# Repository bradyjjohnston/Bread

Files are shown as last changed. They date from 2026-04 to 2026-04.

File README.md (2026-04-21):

# 🍞 SALT - Slice And Loaf Telemetry

> A modular home automation and environmental sensing platform, developed in collaboration with **EE4737** and the open-source [BREAD] project.

---

## Overview

BREAD is a modular embedded systems architecture built around a central **Loaf** board and hot-swappable **Slice** modules. Each slice handles its own sensing or control functionality and communicates back to the loaf over a shared protocol (UART). Together, they form a capable at-home weather station and automation hub.

---

## Architecture

```
┌────────────────────────────────────────┐
│              Loaf (Main Board)         │
│   Central controller with female conn. │
│   handles aggregation, display, logic  │
└────────┬────────┬────────┬─────────────┘
         │        │        │
    ┌────┴──┐ ┌───┴──┐ ┌───┴──┐
    │Slice 1│ │Slice2│ │Slice3│  ...
    │SENSE  │ │ ACT. │ │ OPT. │
    └───────┘ └──────┘ └──────┘
```

- **Loaf** — the main board with female connectors, acts as the central hub
- **Slices** — individual modules that plug into the loaf via edge connectors and expose sensor data or control outputs over UART/I2C

---

## Features

- 🌡️ **Environmental monitoring** — temperature, humidity, pressure (BME280)
- 🌐 **Weather data integration** — pulls external weather API data
- 📡 **Modular slice communication** — UART packet protocol between slices and loaf
- 🔌 **Plug-and-play expansion** — add new slices without redesigning the core system
- 🏠 **Home automation ready** — designed to grow into broader automation use cases

---

## Hardware

| Component | Role |
|---|---|
| LOAF | Sensor slice microcontroller |
| Sense Slice | temp / humidity / pressure sensor / boot sensor |
| Actuation Slice | salt distribution motor control |
| Optics Slice | camera processing and control |
| Power Slice | power outage detection and power distribution |

---

## Communication Protocol

Slices send formatted UART packets to the loaf via DMA when requested by the master MCU. Each packet includes:

- Formatted sensor data

---

## Getting Started

> ⚠️ Hardware required. Software setup instructions coming soon.

1. Clone this repo
2. Open in **STM32CubeIDE**
3. Flash the slice firmware to your Nucleo F303K8
4. Connect the slice to the loaf board via the edge connector
5. Monitor output over UART at `115200` baud

---

## Project Context

This system was developed as part of **EE4737** coursework and builds on the open-source BREAD framework. The goal is a practical, extensible platform for real-world embedded sensing and home automation experimentation.

---

## License

MIT — see `LICENSE` for details.

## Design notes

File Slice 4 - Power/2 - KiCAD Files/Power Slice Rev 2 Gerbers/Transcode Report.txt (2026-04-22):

   ---- Transcoding 'C:\Users\Emily\OneDrive\Desktop\College\Embedded Systems\Power Slice Rev 1\Power Slice Rev 2 Gerbers\Power Slice Rev 1-F_Paste.gbr' ----   Thu Feb 26 17:30:41 2026

D10   --> D100
D11   --> D101
D12   --> D102
D13   --> D103
D14   --> D104
D15   --> D105
D16   --> D106
D17   --> D107
D18   --> D108
D19   --> D109
D20   --> D110
D21   --> D111
D22   --> D112
D23   --> D113
D24   --> D114
D25   --> D115
D26   --> D116
D27   --> D117
D28   --> D118
D29   --> D119
D30   --> D120
D31   --> D121
D32   --> D122
D33   --> D123
D34   --> D124
D35   --> D125
D36   --> D126
D37   --> D127
-----------------------------------------------------------------

   ---- Transcoding 'C:\Users\Emily\OneDrive\Desktop\College\Embedded Systems\Power Slice Rev 1\Power Slice Rev 2 Gerbers\Power Slice Rev 1-F_Silkscreen.gbr' ----   Thu Feb 26 17:30:41 2026

D11   --> D128
D12   --> D129
D13   --> D130
D14   --> D131
D16   --> D132
D17   --> D133
D18   --> D134
-----------------------------------------------------------------

   ---- Transcoding 'C:\Users\Emily\OneDrive\Desktop\College\Embedded Systems\Power Slice Rev 1\Power Slice Rev 2 Gerbers\Power Slice Rev 1-In1_Cu.gbr' ----   Thu Feb 26 17:30:41 2026

D10   --> D135
D11   --> D136
D12   --> D137
D13   --> D138
D14   --> D139
D15   --> D140
D16   --> D141
D17   --> D142
D18   --> D143
D19   --> D144
D20   --> D145
D21   --> D146
D22   --> D147
D23   --> D148
D24   --> D149
D25   --> D150
D26   --> D151
D27   --> D152
D28   --> D153
D29   --> D154
D30   --> D155
D31   --> D156
D32   --> D157
-----------------------------------------------------------------

   ---- Transcoding 'C:\Users\Emily\OneDrive\Desktop\College\Embedded Systems\Power Slice Rev 1\Power Slice Rev 2 Gerbers\Power Slice Rev 1-In2_Cu.gbr' ----   Thu Feb 26 17:30:41 2026

D10   --> D158
D11   --> D159
D12   --> D160
D13   --> D161
D14   --> D162
D15   --> D163
D16   --> D164
D17   --> D165
D18   --> D166
D19   --> D167
D20   --> D168
D21   --> D169
D22   --> D170
D23   --> D171
D24   --> D172
D25   --> D173
D26   --> D174
D27   --> D175
D28   --> D176
D29   --> D177
D30   --> D178
D31   --> D179
D32   --> D180
D33   --> D181
D34   --> D182
D35   --> D183
-----------------------------------------------------------------

   ---- Transcoding 'C:\Users\Emily\OneDrive\Desktop\College\Embedded Systems\Power Slice Rev 1\Power Slice Rev 2 Gerbers\Power Slice Rev 1-B_Cu.gbr' ----   Thu Feb 26 17:30:41 2026

D10   --> D184
D11   --> D185
D12   --> D186
D13   --> D187
D14   --> D188
D15   --> D189
D16   --> D190
D17   --> D191
D18   --> D192
D19   --> D193
D20   --> D194
D21   --> D195
D22   --> D196
D23   --> D197
D24   --> D198
D25   --> D199
D26   --> D200
D27   --> D201
D28   --> D202
D29   --> D203
D30   --> D204
D31   --> D205
D32   --> D206
D33   --> D207
D34   --> D208
D35   --> D209
D36   --> D210
D37   --> D211
D38   --> D212
D39   --> D213
D40   --> D214
-----------------------------------------------------------------

   ---- Transcoding 'C:\Users\Emily\OneDrive\Desktop\College\Embedded Systems\Power Slice Rev 1\Power Slice Rev 2 Gerbers\Power Slice Rev 1-B_Mask.gbr' ----   Thu Feb 26 17:30:41 2026

D12   --> D215
D13   --> D216
D14   --> D217
D15   --> D218
D16   --> D219
D17   --> D220
D18   --> D221
D19   --> D222
D20   --> D223
D21   --> D224
D22   --> D225
D23   --> D226
D24   --> D227
D25   --> D228
D26   --> D229
D27   --> D230
D28   --> D231
D29   --> D232
D30   --> D233
D31   --> D234
-----------------------------------------------------------------

   ---- Transcoding 'C:\Users\Emily\OneDrive\Desktop\College\Embedded Systems\Power Slice Rev 1\Power Slice Rev 2 Gerbers\Power Slice Rev 1-B_Paste.gbr' ----   Thu Feb 26 17:30:41 2026

D10   --> D235
D11   --> D236
-----------------------------------------------------------------

   ---- Transcoding 'C:\Users\Emily\OneDrive\Desktop\College\Embedded Systems\Power Slice Rev 1\Power Slice Rev 2 Gerbers\Power Slice Rev 1-B_Silkscreen.gbr' ----   Thu Feb 26 17:30:41 2026

D10   --> D237
D11   --> D238
D12   --> D239
D13   --> D240
D14   --> D241
-----------------------------------------------------------------

   ---- Transcoding 'C:\Users\Emily\OneDrive\Desktop\College\Embedded Systems\Power Slice Rev 1\Power Slice Rev 2 Gerbers\Power Slice Rev 1-Edge_Cuts.gbr' ----   Thu Feb 26 17:30:41 2026

D10   --> D242
-----------------------------------------------------------------

   ---- Transcoding 'C:\Users\Emily\OneDrive\Desktop\College\Embedded Systems\Power Slice Rev 1\Power Slice Rev 2 Gerbers\Power Slice Rev 1-F_Cu.gbr' ----   Thu Feb 26 17:30:41 2026

D10   --> D243
D11   --> D244
D12   --> D245
D13   --> D246
D14   --> D247
D15   --> D248
D16   --> D249
D17   --> D250
D18   --> D251
D19   --> D252
D20   --> D253
D21   --> D254
D22   --> D255
D23   --> D256
D24   --> D257
D25   --> D258
D26   --> D259
D27   --> D260
D28   --> D261
D29   --> D262
D30   --> D263
D31   --> D264
D32   --> D265
D33   --> D266
D34   --> D267
D35   --> D268
D36   --> D269
D37   --> D270
D38   --> D271
D39   --> D272
D40   --> D273
D41   --> D274
D42   --> D275
D43   --> D276
D44   --> D277
D45   --> D278
D46   --> D279
D47   --> D280
D48   --> D281
D49   --> D282
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
-----------------------------------------------------------------

   ---- Transcoding 'C:\Users\Emily\OneDrive\Desktop\College\Embedded Systems\Power Slice Rev 1\Power Slice Rev 2 Gerbers\Power Slice Rev 1-PTH-drl_map.gbr' ----   Thu Feb 26 17:30:47 2026

D10   --> D292
D11   --> D293
D12   --> D294
D13   --> D295
D14   --> D296
-----------------------------------------------------------------

   ---- Transcoding 'C:\Users\Emily\OneDrive\Desktop\College\Embedded Systems\Power Slice Rev 1\Power Slice Rev 2 Gerbers\Power Slice Rev 1-PTH-drl.gbr' ----   Thu Feb 26 17:30:54 2026

D10   --> D297
D11   --> D298
D12   --> D299
D13   --> D300
D14   --> D301
D15   --> D302
D16   --> D303
D17   --> D304
D18   --> D305
D19   --> D306
-----------------------------------------------------------------

   ---- Transcoding 'C:\Users\Emily\OneDrive\Desktop\College\Embedded Systems\Power Slice Rev 1\Power Slice Rev 2 Gerbers\Power Slice Rev 1-PTH-drl_map.gbr' ----   Thu Feb 26 17:30:54 2026

D10   --> D307
D11   --> D308
D12   --> D309
D13   --> D310
D14   --> D311
-----------------------------------------------------------------

   ---- Transcoding 'C:\Users\Emily\OneDrive\Desktop\College\Embedded Systems\Power Slice Rev 1\Power Slice Rev 2 Gerbers\Power Slice Rev 1-NPTH-drl.gbr' ----   Thu Feb 26 17:30:55 2026

D10   --> D312
-----------------------------------------------------------------

   ---- Transcoding 'C:\Users\Emily\OneDrive\Desktop\College\Embedded Systems\Power Slice Rev 1\Power Slice Rev 2 Gerbers\Power Slice Rev 1-NPTH-drl_map.gbr' ----   Thu Feb 26 17:30:55 2026

D10   --> D313
D11   --> D314
D12   --> D315
D13   --> D316
-----------------------------------------------------------------

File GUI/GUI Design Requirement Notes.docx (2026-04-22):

Tasks:

- communication between host laptop and mcu
  - Pyserial: library to interact with mcu over serial wire or usb
    - https://pyserial.readthedocs.io/en/latest/
- hosting GUI on laptop inside:
  - Tkinter: simple easy to use python toolkit for building GUI which I have experience with
- Kalman Filter
  - https://thekalmanfilter.com/kalman-filter-explained-simply/
  - https://en.wikipedia.org/wiki/Kalman_filter
  - https://web.mit.edu/kirtley/kirtley/binlustuff/literature/control/Kalman%20filter.pdf
  - FilterPy
    - library with great documentation and specific kalman module that should simplify setup
    - https://filterpy.readthedocs.io/en/latest/kalman/KalmanFilter.html
  - https://www.geeksforgeeks.org/python/kalman-filter-in-python/
- Communication
  - collaborate with other teams in order to set up system on I2C commands:
    - one-byte for which part of project is being addressed
    - one-byte for communication or command being sent
    - additional bytes need to be determined for data transmit: decide max amount for one comm and use that
  - DMA on interrupt for receiving

Packet design for USB to MCU communication:

MCU:

Slice ID, 1 Byte

- first 4 bits= slice identification; second 4 bits slice portion command
  - 0x0 loaf
  - 0x1 actuation
    - 0x0 boot mechanism
    - 0x1 heating element
    - 0x2 salt spreading
  - 0x2 optics
    - 0x0 motion/presence
    - 0x1 snow height
    - 0x2 precipitation state
    - 0x3 level of light
  - 0x3 power
    - 0x0 power outage info
    - 0x1 power draw information
    - 0x2 E-stop
  - 0x4 sensing
    - 0x0 temperature info
    - 0x1 humidity info
    - 0x2 boot detection
    - 0x3 off-board weather data request

Length, 1 Byte:

- length of upcoming data bytes

Payload, variable length

- data to be transmitted

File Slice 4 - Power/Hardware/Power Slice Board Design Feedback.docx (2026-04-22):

General Comments

- Get rough power budgeting per slice (each board takes about 200 mA)
- Double-check footprints
- (Non-critical) Determine why the diodes are on the buck converter

Schematic

- Check footprints and match barrel jacks
- Need more amperage for the entire board (output 1.5 - 2A), make sure we can handle it
- Add another set of bulk capacitors on the 3v3 and 5v
- Tie MFP from the RTC to one of the Nucleo I/O pins, add a decoupling capacitor and pullup resistor to the MFP line
- Use a 36-pin edge connection symbol
- Find out the power draw on the 0-ohms and ensure that it can handle the current draw (0805 appears that it’s only rated for 1/8 W?)
- Slow-blow fuse for lines going out to the motors and actuation slice
- Add 3V3 and 5V inputs bypassing the bucks - need to add bypasses for the bucks (0-ohm jumper)

Board Design

- Move more elements to the back if possible
- Determine the amp limit through the edge connector, make sure that it is also limited with a fuse for safety (3A per contact)
  - Keep this conservative!
  - Put multiple traces for each 5V (?) to power each board
- Size traces and vias
- Add slits under each current sensor
- Use the recommended layout for the RTC
- Tune capacitors for the RTC
- Make the electrolytic capacitors traces thicker

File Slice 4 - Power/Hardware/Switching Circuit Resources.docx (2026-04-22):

https://electronics.stackexchange.com/questions/608611/switching-between-power-sources-part-2

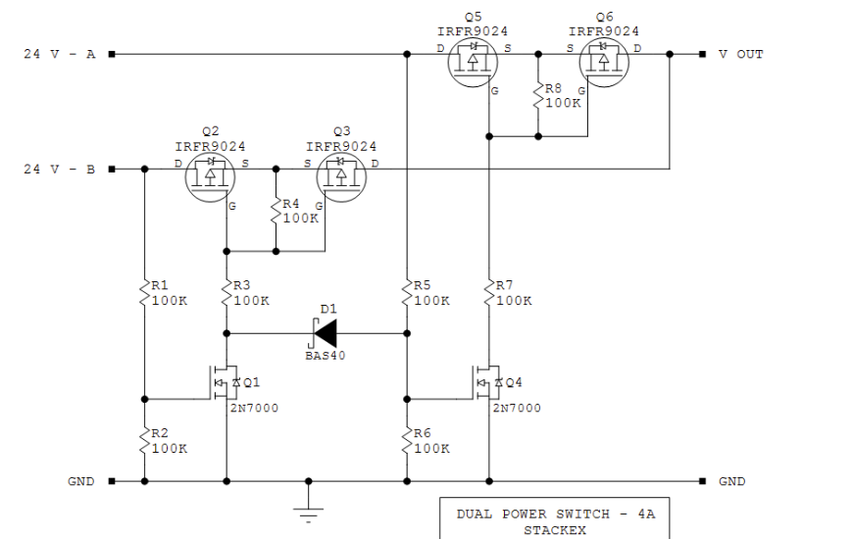
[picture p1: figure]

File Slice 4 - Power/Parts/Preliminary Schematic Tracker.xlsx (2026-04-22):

Subsystem | Parts Selected? | Schematic Created? | Responsibility
SLICE-LOAF Interface | In-Progress | No | N/A
Power Input: Benchtop | No | No | Emily
Power Input: Wall Power | No | No | Emily
Indicator LED | Yes | Yes | Joe
Outage Detection RTC | Yes | Yes | Joe
Full-System Circuit Break | In-Progress | No | Emily
Subsystem Circuit Break | In-Progress | No | Emily
3.3 V Conversion | In-Progress | No | Emily
5.0 V Conversion | In-Progress | No | Emily
Measured Power Draw | Yes | Yes | Joe
Displayed Power Draw | Yes | Yes | Joe

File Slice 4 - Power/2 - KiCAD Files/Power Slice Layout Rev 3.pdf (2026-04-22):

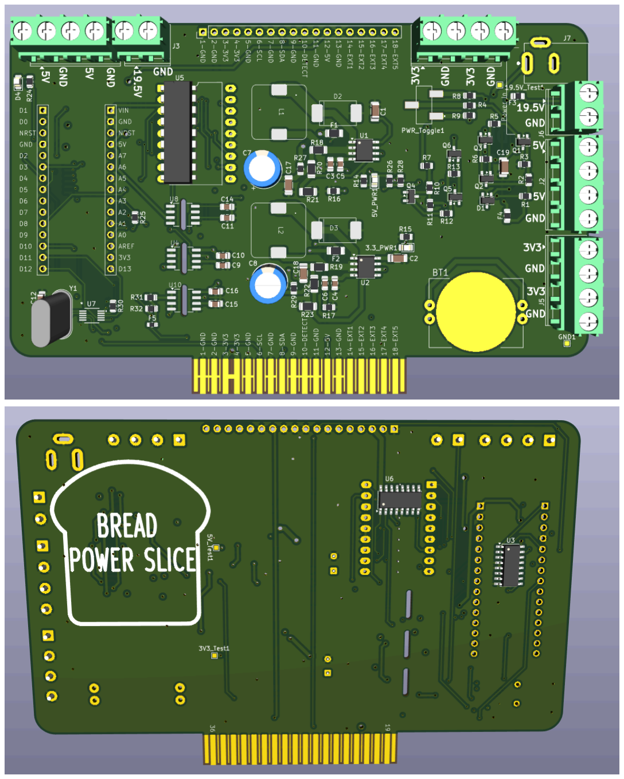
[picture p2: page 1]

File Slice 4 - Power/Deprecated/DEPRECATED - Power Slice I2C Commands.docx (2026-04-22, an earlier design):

The peripheral address of the Power Slice is 0x12.

The following are the commands that the LOAF can send the power slice via I2C:

| Command Value | Packet Length
Power Draw | 0xA | 4
Outage Time | 0xB | 4
Outage Since Last Transmission | 0xC | 1

Power Draw (0xA)

- Gives the power draw of the system in mW. WHAT IS THE ORDER OF DATA TRANSMISSION?

Outage Time (0xB)

- Gives the amount of time that the system has gone without power. If the outage time is zero, then the system has not lost power.
- INCLUDE THE DEFINITION OF EACH PIN / BYTE

Outage Since Last Transmission (0xC)

- Returns 0xF if there has been an outage since the last time this command has been run, and returns 0x0 otherwise.

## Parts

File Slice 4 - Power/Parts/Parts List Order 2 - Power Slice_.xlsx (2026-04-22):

Part | Function | Link | Footprint | Quantity | Datasheet? | Slice
SF-0603S040-2 | Fuse, 400 mA | https://www.digikey.com/en/products/detail/bourns-inc/SF-0603S040-2/8747904 | 603 | 5 | Yes | Power | X
CL31A106KBHNNNE | 10 uF Capacitor | https://www.digikey.com/en/products/detail/samsung-electro-mechanics/CL31A106KBHNNNE/3888534 | 1206 | 3 | Yes | Power | X
ACS725LLCTR-05AB-T | Current Sensor | https://www.digikey.com/en/products/detail/allegro-microsystems/ACS725LLCTR-05AB-T/10498747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..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 |  | 1 | Yes | Power | X
RC0805JR-070RL | 0-Ohm Jumper | https://www.digikey.com/en/products/detail/yageo/RC0805JR-070RL/728216 | 805 | 10 |  |  | X
SF-1206S150-2 | Fuse, 1.5 A | https://www.digikey.com/en/products/detail/bourns-inc/SF-1206S150-2/1948177 | 1206 | 4 |  |  | X
3413.0116.22 | Fuse, 1.25A | https://www.digikey.com/en/products/detail/schurter-inc/3413-0116-22/669877 | 1206 | 4

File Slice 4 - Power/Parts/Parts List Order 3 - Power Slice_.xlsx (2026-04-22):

Part | Function | Link | Footprint | Quantity | Datasheet? | Slice
n/a | Universal Laptop Charger | https://www.amazon.com/Certification-Universal-Compatible-Ultrabook-Chromebook/dp/B09NM28SB4 |  |  | No | Power | X
PJ-202BH | Power Barrel Connector Jack 2.50mm ID (0.098"), 5.50mm OD (0.217") Through Hole, Right Angle | https://www.digikey.com/en/products/detail/same-sky-formerly-cui-devices/PJ-202BH/408451 |  |  |  |  | X
PJ-202B | Power Barrel Connector Jack 2.50mm ID (0.098"), 5.50mm OD (0.217") Through Hole, Right Angle | https://www.digikey.com/en/products/detail/same-sky-formerly-cui-devices/PJ-202B/252008 |  |  |  |  | X
ADC-033-2 | Power Barrel Connector Jack 2.50mm ID (0.098"), 5.50mm OD (0.217") Through Hole, Right Angle | https://www.digikey.com/en/products/detail/adam-tech/ADC-033-2/9831639
KLDHCX-0202-BC-1 | Power Barrel Connector Jack 2.50mm ID (0.098"), 5.50mm OD (0.217") Through Hole, Right Angle | https://www.digikey.com/en/products/detail/kycon-inc/KLDHCX-0202-BC-1/13901306
KLDHCX-0202-B-LT | Power Barrel Connector Jack 2.50mm ID (0.098"), 5.50mm OD (0.217") Through Hole, Right Angle | https://www.digikey.com/en/products/detail/kycon-inc/KLDHCX-0202-B-LT/10246542

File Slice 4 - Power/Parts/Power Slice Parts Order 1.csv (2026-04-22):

Description | Part Number | Quantity | URL
RTC | MCP79510T-I/MS | 1 | https://www.digikey.com/en/products/detail/microchip-technology/MCP79510T-I-MS/3177022
Crystal Tuning Fork | VT200F-6PF20PPM | 1 | https://www.digikey.com/en/products/detail/seiko-instruments/VT200F-6PF20PPM/1626715
Buck Converter | L6902D013TR | 2 | https://www.digikey.com/en/products/detail/stmicroelectronics/L6902D013TR/1037941
Screw Terminal (4 port) | 1935187 | 4 | https://www.digikey.com/en/products/detail/phoenix-contact/1935187/568616
Screw Terminal (2 port) | 691137710002 | 2 | https://www.digikey.com/en/products/detail/w%C3%BCrth-elektronik/691137710002/6644051
Laptop Charger | n/a | 1 | https://www.amazon.com/Govolia-Charger-Compatible-Business-Convenient/dp/B081C8TRLP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
Diode, 3A Schottky | MBRS360T3G | 2 | https://www.digikey.com/en/products/detail/onsemi/MBRS360T3G/918646?s=N4IgTCBcDaILICEBKBlAzANgAwBU0HEQBdAXyA
Current Sensor | ACS725LLCTR-05AB-T | 2 | https://www.digikey.com/en/products/detail/allegro-microsystems/ACS725LLCTR-05AB-T/10498747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..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
0.1 uF/100nF - 0805 | CL21B104KBCNNNC | 7 | https://www.digikey.com/en/products/detail/samsung-electro-mechanics/CL21B104KBCNNNC/3886661
1 nF - 0805 | C0805C102J5GACTU | 5 | https://www.digikey.com/en/products/detail/kemet/C0805C102J5GACTU/411135
1 pF - 0805 | CML0805C0G1R0CT50V | 5 | https://www.digikey.com/en/products/detail/stackpole-electronics-inc/CML0805C0G1R0CT50V/10659964
10 pF - 0805 | QSCT251Q100J1GV001E | 5 | https://www.digikey.com/en/products/detail/johanson-technology-inc/QSCT251Q100J1GV001E/1833671
1k - 0805 | RMCF0805FT1K00 | 4 | https://www.digikey.com/en/products/detail/stackpole-electronics-inc/RMCF0805FT1K00/1760090
10k - 0805 | RMCF0805FT10K0 | 4 | https://www.digikey.com/en/products/detail/stackpole-electronics-inc/RMCF0805FT10K0/1760676
2x 7 Segment Display | LTD-6940HR | 1 | https://www.digikey.com/en/products/detail/liteon/LTD-6940HR/3199144
1x8 Multiplexer | NLV74ACT138DR2G | 2 | https://www.digikey.com/en/products/detail/onsemi/NLV74ACT138DR2G/5257279
3V Coin Cell | CR2032 | 2 | https://www.digikey.com/en/products/detail/panasonic-energy/CR2032/31939
Coin Cell Clip | BAT-HLD-001-THM | 1 | https://www.digikey.com/en/products/detail/te-connectivity-linx/BAT-HLD-001-THM/3044009
Barrel Jack | PJ-202A | 1 | https://www.digikey.com/en/products/detail/same-sky-formerly-cui-devices/PJ-202A/252007
LED - red - 0805 | LS R976-NR-1-0-20-R18 | 3 | https://www.digikey.com/en/products/detail/ams-osram-usa-inc/LS-R976-NR-1-0-20-R18/1227987
Mosfet | DMP2123L-7 | 6 | https://www.digikey.com/en/products/detail/diodes-incorporated/DMP2123L-7/1964692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
Fuse, 0.5A - 0805 | MFU0805FF00500P500 | 10 | https://www.digikey.com/en/products/detail/vishay/MFU0805FF00500P500/1202615
Fuse, 3.5A - 0805 | MFU0805FF03500P100 | 5 | https://www.digikey.com/en/products/detail/vishay/MFU0805FF03500P100/1206499
Fuse, 3A - 0805 | MFU0805FF03000P500 | 5 | https://www.digikey.com/en/products/detail/vishay/MFU0805FF03000P500/1202626
100k - 0805 | RC0805FR-07100KL | 11 | https://www.digikey.com/en/products/detail/yageo/RC0805FR-07100KL/727544
10uF - 1206 | CL31A106KBHNNNE | 5 | https://www.digikey.com/en/products/detail/samsung-electro-mechanics/CL31A106KBHNNNE/3888534
0.1 Ohm - 1206 | RL1206FR-070R1L | 4 | https://www.digikey.com/en/products/detail/yageo/RL1206FR-070R1L/2827660
0.2 Ohm - 1206 | RL1206FR-070R2L | 4 | https://www.digikey.com/en/products/detail/yageo/RL1206FR-070R2L/2827672
100uF - elec, 50V | UVK1H101MPD | 5 | https://www.digikey.com/en/products/detail/nichicon/UVK1H101MPD/2539403
3.3k - 0805 | RC0805FR-073K3L | 5 | https://www.digikey.com/en/products/detail/yageo/RC0805FR-073K3L/727813
4.3k - 1206 | RC1206FR-074K3L | 4 | https://www.digikey.com/en/products/detail/yageo/RC1206FR-074K3L/728872
220pF - 0805 | CL21C221JBANNNC | 5 | https://www.digikey.com/en/products/detail/samsung-electro-mechanics/CL21C221JBANNNC/3886822
5.1k - 0805 | RC0805FR-075K1L | 5 | https://www.digikey.com/en/products/detail/yageo/RC0805FR-075K1L/727988
22nF - 0805 | C0805C223K5RACTU | 5 | https://www.digikey.com/en/products/detail/kemet/C0805C223K5RACTU/411162
13k - 1206 | RC1206FR-0713KL | 4 | https://www.digikey.com/en/products/detail/yageo/RC1206FR-0713KL/728532
5.6k - 1206 | RC1206FR-075K6L | 4 | https://www.digikey.com/en/products/detail/yageo/RC1206FR-075K6L/728962
22uH - 8mm | P1171.223NLT | 2 | https://www.digikey.com/en/products/detail/pulse-electronics/P1171-223NLT/2266798
Diode, 200 mA Schotty | BAS40 | 1 | https://www.digikey.com/en/products/detail/diotec-semiconductor/BAS40/13155844
3.3k - 1206 | RC1206FR-073K3L | 4 | https://www.digikey.com/en/products/detail/yageo/RC1206FR-073K3L/728766
Switch | JS102011SCQN | 1 | https://www.digikey.com/en/products/detail/c-k/JS102011SCQN/3753547
0-0hm - 0805 | RC0805JR-070RL | 10 | https://www.digikey.com/en/products/detail/yageo/RC0805JR-070RL/728216

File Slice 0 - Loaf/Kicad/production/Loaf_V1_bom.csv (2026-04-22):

Designator | Footprint | Quantity | Value | LCSC Part #
C1, C17, C2, C7, C8 | 0805 | 5 | 0.1uF
C10, C11, C12, C13, C14, C15, C16, C3, C4, C5, C6, C9 | 0805 | 12 | 10uF
D1 | 0805 | 1 | USER LED1
D2 | 0805 | 1 | USER LED2
J1 | TerminalBlock_RND_205-00234_1x04_P5.08mm_Horizontal | 1 | Power Input Terminal
J2, J3, J4, J5 | EdgeConnector | 4 | 36p Edge Connector
R1, R2, R3, R4, R5, R6, R7, R8, R9 | 0805 | 9 | 4.7k
SW1 | SW_PUSH_6mm_H5mm | 1 | BOOT
U1 | MODULE_NUCLEO-F303K8 | 1 | NUCLEO-F303K8

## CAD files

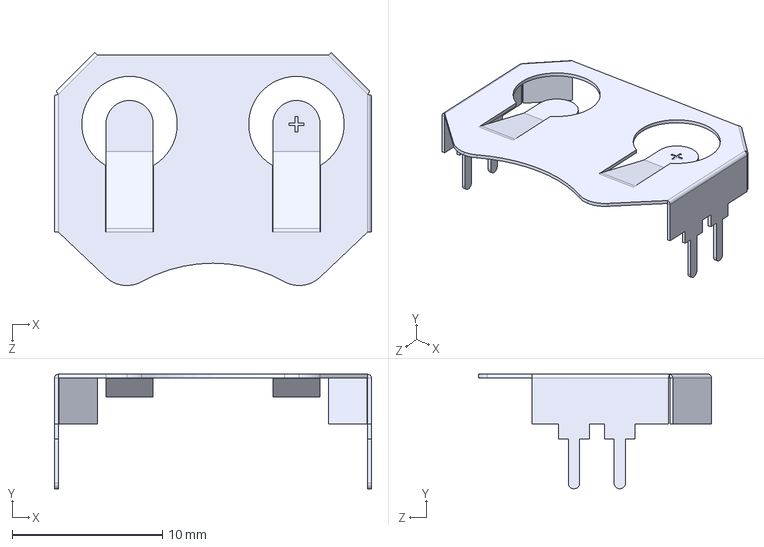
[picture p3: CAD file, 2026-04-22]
Slice 4 - Power/2 - KiCAD Files/Custom Footprints/BAT_HLD_001_THM/BAT-HLD-001-THM.step
21.1 x 7.62 x 15.5 mm

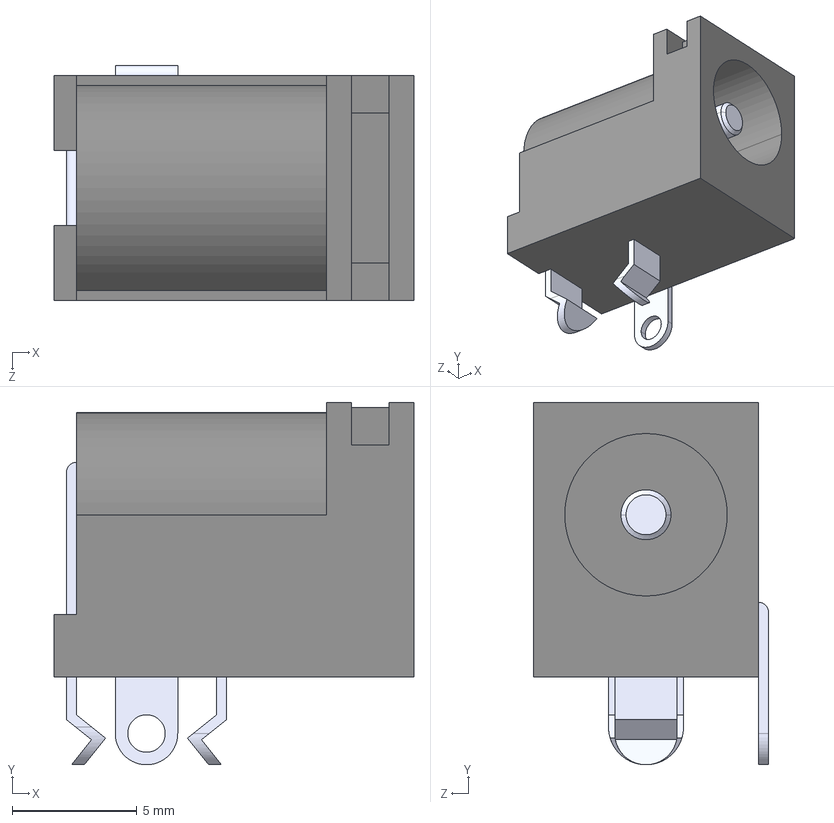
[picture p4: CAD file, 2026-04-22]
Slice 4 - Power/2 - KiCAD Files/Custom Footprints/PJ_202A/PJ-202A.step
14.4 x 14.5 x 9.40 mm

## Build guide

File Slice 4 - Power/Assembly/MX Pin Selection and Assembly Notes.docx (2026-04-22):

# MX Pin Assignments

MX Pin Name | NUCLEO Pin Name | Schematic Pin Name
PA_9 | D1 | D1
PA_10 | D0 | D0
PA_12 | D2 | D2
PB_0 | D3 | D3
PB_7 | D4 | I2C_DSA
PB_6 | D5 | I2C_SCL
PF_0 | D7 | D7
PF_1 | D8 | D8
PA_8 | D9 | D9
PA_11 | D10 | D10
PB_5 | D11 | SI
PF_4 | D12 | SO
PA_4 | A3 | CS* (NSS)
PA_3 | A2 | ADC2/2
PA_1 | A1 | ADC1/2
PA_0 | A0 | ADC1/1
PB_3 | D13 | SCK

# Board Assembly Notes

### Trace Cuts:

- Always make sure to double-check with the schematic before cutting traces!
- Cut the trace attached to the MCU’s pin D0. Jump D0 to the corresponding pin on the seven-segment display. Keep the original D10 tied to the MFP on the RTC.
- Cut traces between the signal outs for U4 and U10 (current sensors). Jump one of the signal outs to pin A2 on the MCU. Note that pin A2 is disconnected from the PCB
  - We chose to cut the connection on U4

### Misc:

- Make sure to assemble the board in stages (power, sensing, then MCU).

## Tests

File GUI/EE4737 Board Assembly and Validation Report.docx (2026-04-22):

EE4737 Board Assembly and Validation Report

John Terhaar & Katelyn Spolnicki

EE4737 L02 GUI Subteam

Alex Riebe

For our board assembly since we are the GUI subteam and we offloaded the LOAF design to the Sense slice we decided to focus on establishing basic GUI functionality and communication. This included making a functional GUI to be run on the laptop with python and making that program be able to communicate with the mcu via a USB with UART. This was done on the Nucleo board with the same mcu because of the inability to use the actual LOAF as it is assembled. In order to create a GUI a python file utilizing Tkinter a useful standard python library for such tasks.The GUI currently contains a simple display of information, control buttons for project functionalities, a command line interface, a camera feed placeholder, and a basic kalman prediction filter with fake data. Most of the backend of this GUI is not set up yet however an STM32Cube project was created with basic UART serial communication that is done over the same usb cord used for programming and debugging and connection. This connection was tested successfully using the screen linux terminal command to view a "Hello World" message sent from the mcu. Then a basic message packet design was created drawing from online sources and class discussions. This design is documented in the GUI Design Requirement Notes.pdf file submitted. This was set up in the python project and tested sending messages to the mcu but the mcu side is not fully set up to receive the messages in the correct format but was able to receive the messages just as uints and not raw hex bytes. Still left to be done is to improve the communication between mcu and pc as well as set up communication over I2C with all the Slices and adapt the packet design for this I2C bus. On the the PC side the backend for all the different GUI parts needs to be done as well as improving the GUI design and converting the python project to a .exe file that can be ran from the PC homescreen that also would require more error handling especially when no mcu is connected or it is disconnected.

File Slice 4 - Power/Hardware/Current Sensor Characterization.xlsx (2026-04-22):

ADC0 | ADC1 | ADC2 | Constant | Output Power
2038 | 2054 | 2054 | 1 | 0.95
2086 | 2090 | 2103 | 1 | 1.14
2088 | 2079 | 2058 | 1 | 1.14
2092 | 2084 | 2080 | 1 | 1.33
2085 | 2072 | 2073 | 1 | 1.52
2091 | 2082 | 2076 | 1 | 1.52
2090 | 2092 | 2102 | 1 | 1.52
2109 | 2105 | 2087 | 1 | 1.52
2089 | 2102 | 2113 | 1 | 1.52
2079 | 2071 | 2052 | 1 | 1.52
2071 | 2073 | 2087 | 1 | 1.71
2066 | 2079 | 2094 | 1 | 1.71
2088 | 2089 | 2096 | 1 | 1.71
2093 | 2105 | 2099 | 1 | 1.71
2126 | 2131 | 2121 | 1 | 1.71
2054 | 2063 | 2065 | 1 | 1.71
2062 | 2069 | 2083 | 1 | 1.71
2064 | 2074 | 2078 | 1 | 1.9
2095 | 2086 | 2085 | 1 | 1.9
2118 | 2124 | 2135 | 1 | 1.9
2158 | 2148 | 2134 | 1 | 2.09
2117 | 2124 | 2122 | 1 | 2.09
2111 | 2124 | 2128 | 1 | 2.09
2120 | 2109 | 2099 | 1 | 2.09
2136 | 2147 | 2151 | 1 | 2.09
2141 | 2134 | 2139 | 1 | 2.09
2140 | 2130 | 2116 | 1 | 2.09
2146 | 2142 | 2144 | 1 | 2.28
2116 | 2119 | 2131 | 1 | 2.28
2131 | 2128 | 2136 | 1 | 2.28
2113 | 2105 | 2090 | 1 | 2.28
2131 | 2127 | 2114 | 1 | 2.28
2134 | 2120 | 2112 | 1 | 2.28
2130 | 2127 | 2137 | 1 | 2.28
2155 | 2145 | 2134 | 1 | 2.47
2151 | 2157 | 2170 | 1 | 2.47
2147 | 2146 | 2139 | 1 | 2.47
2093 | 2096 | 2096 | 1 | 2.47
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

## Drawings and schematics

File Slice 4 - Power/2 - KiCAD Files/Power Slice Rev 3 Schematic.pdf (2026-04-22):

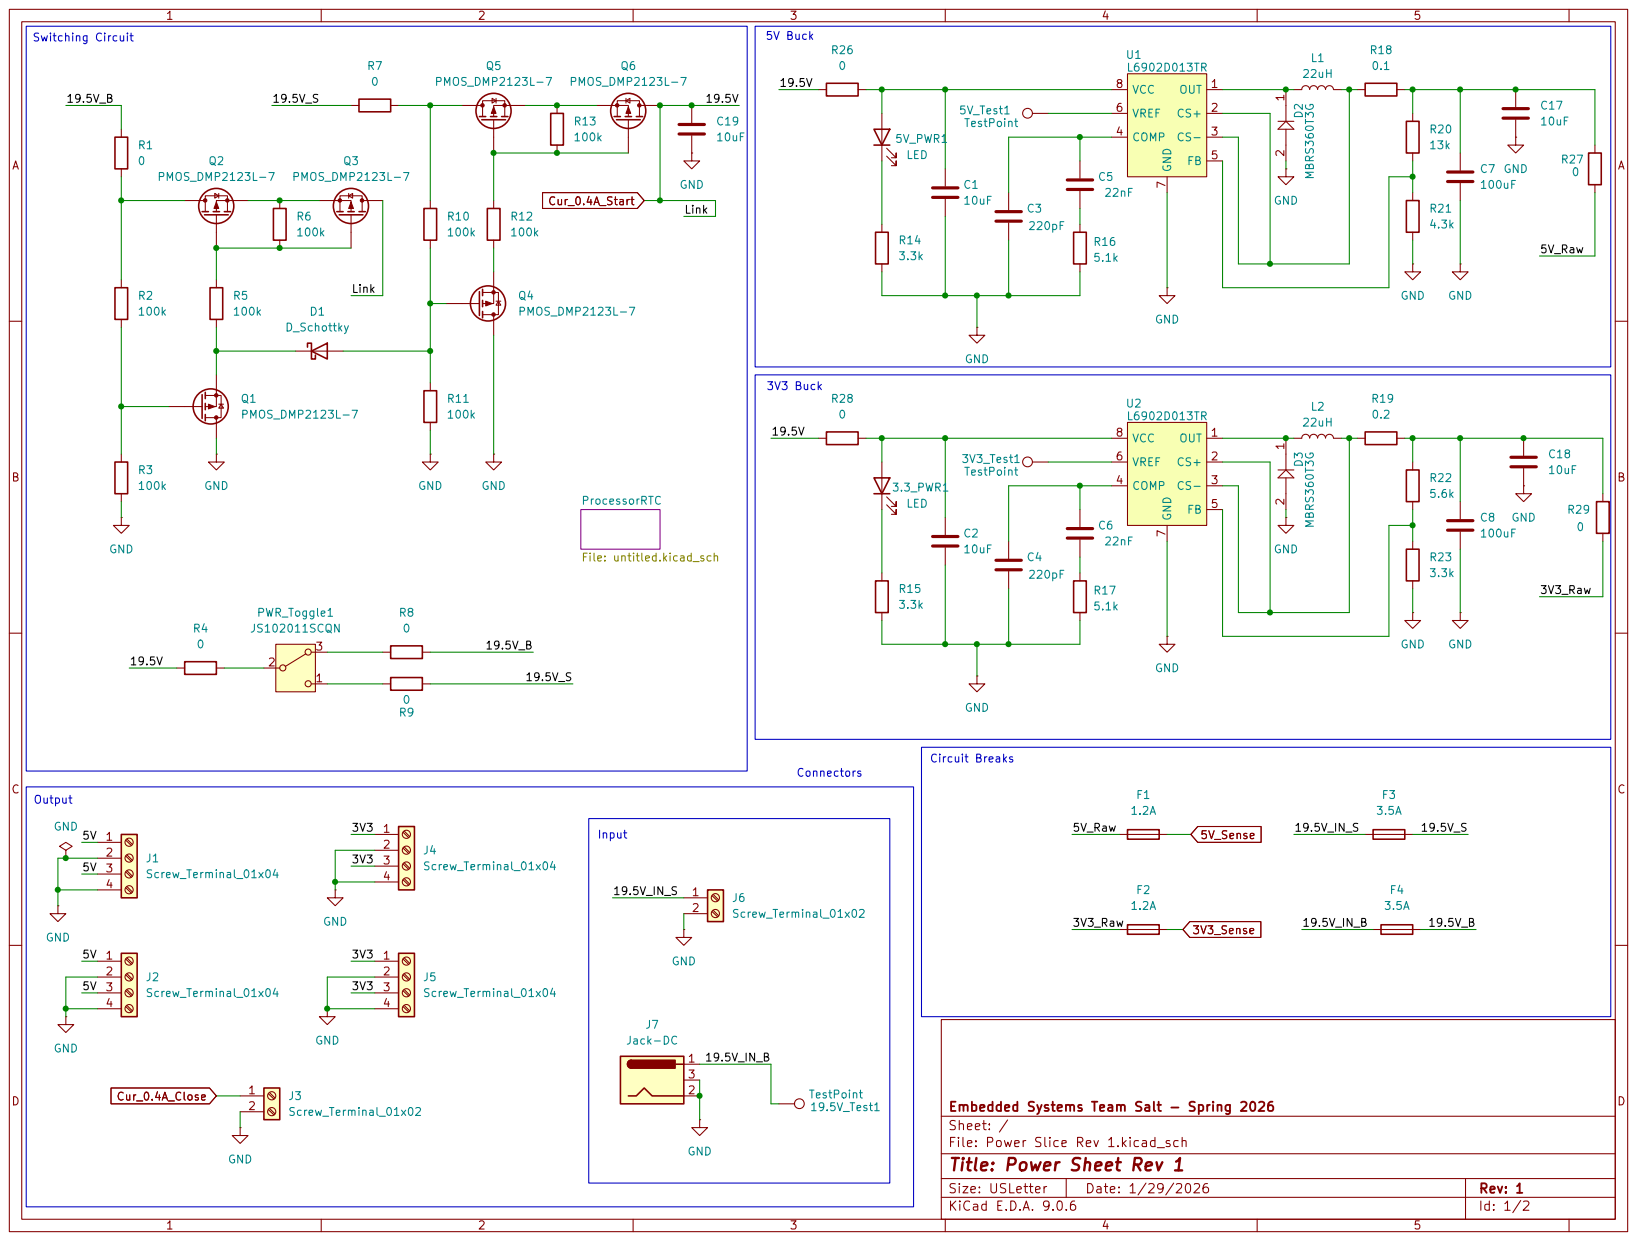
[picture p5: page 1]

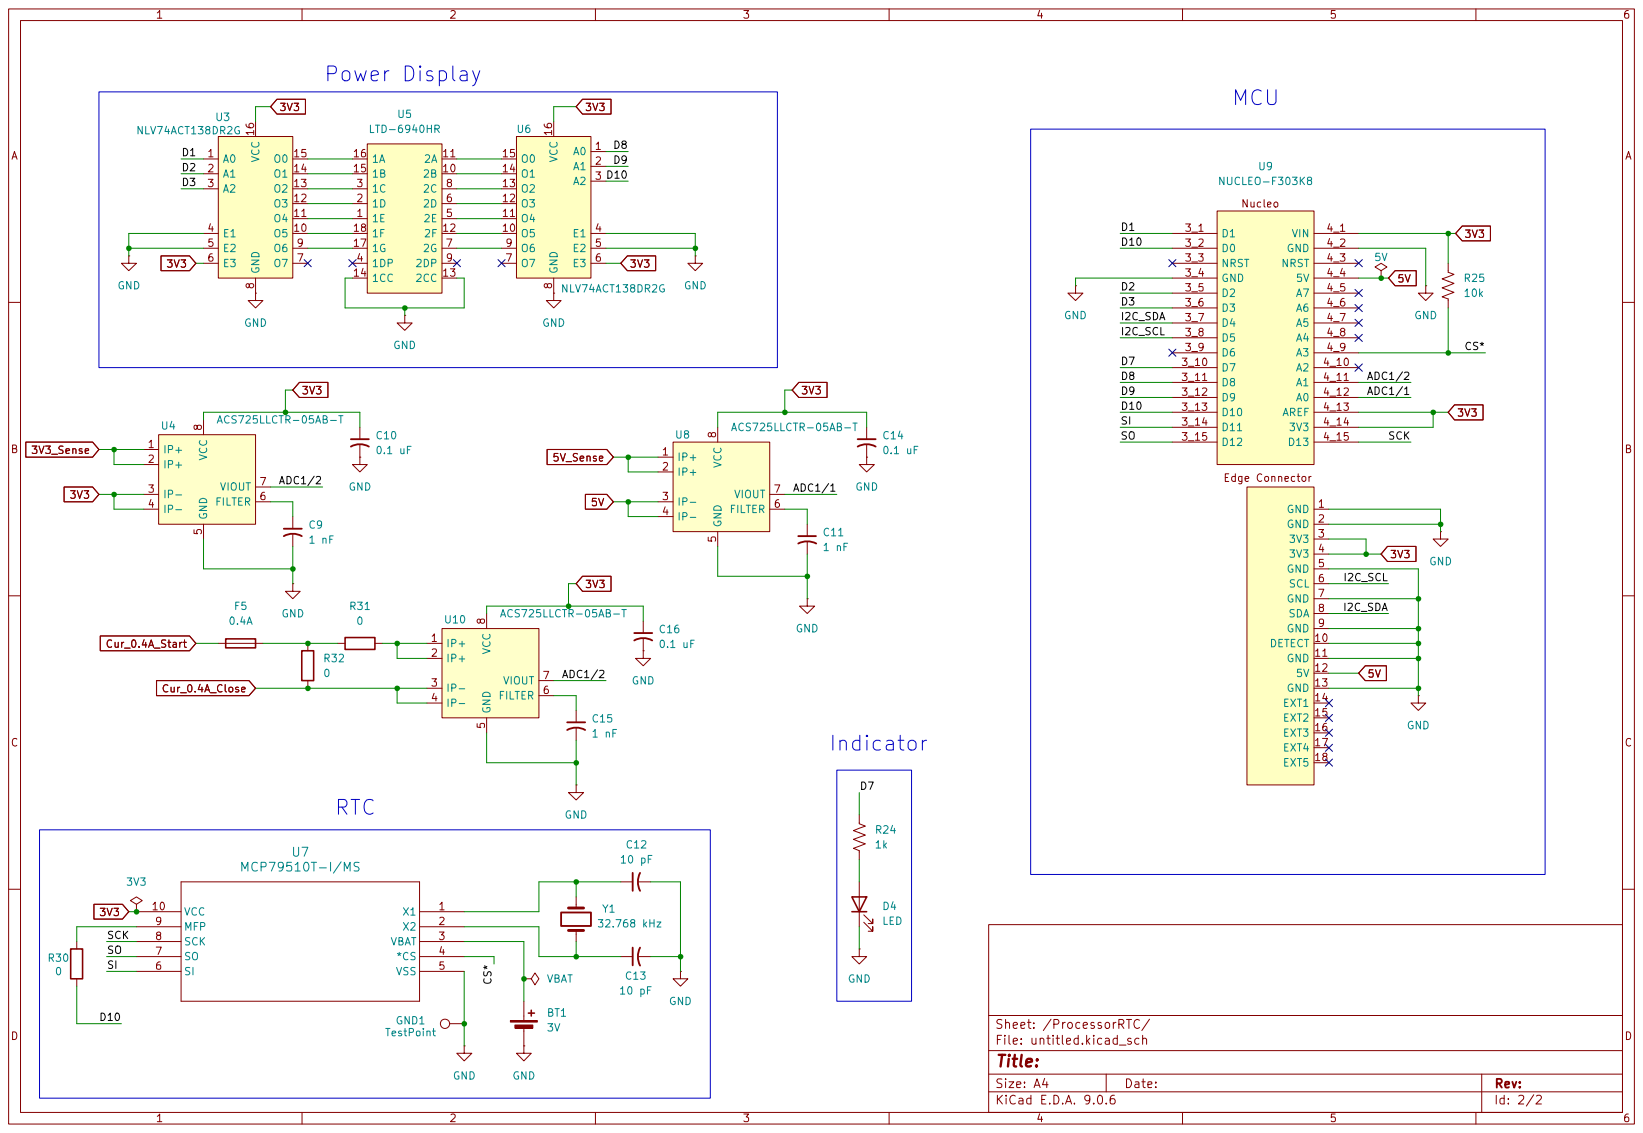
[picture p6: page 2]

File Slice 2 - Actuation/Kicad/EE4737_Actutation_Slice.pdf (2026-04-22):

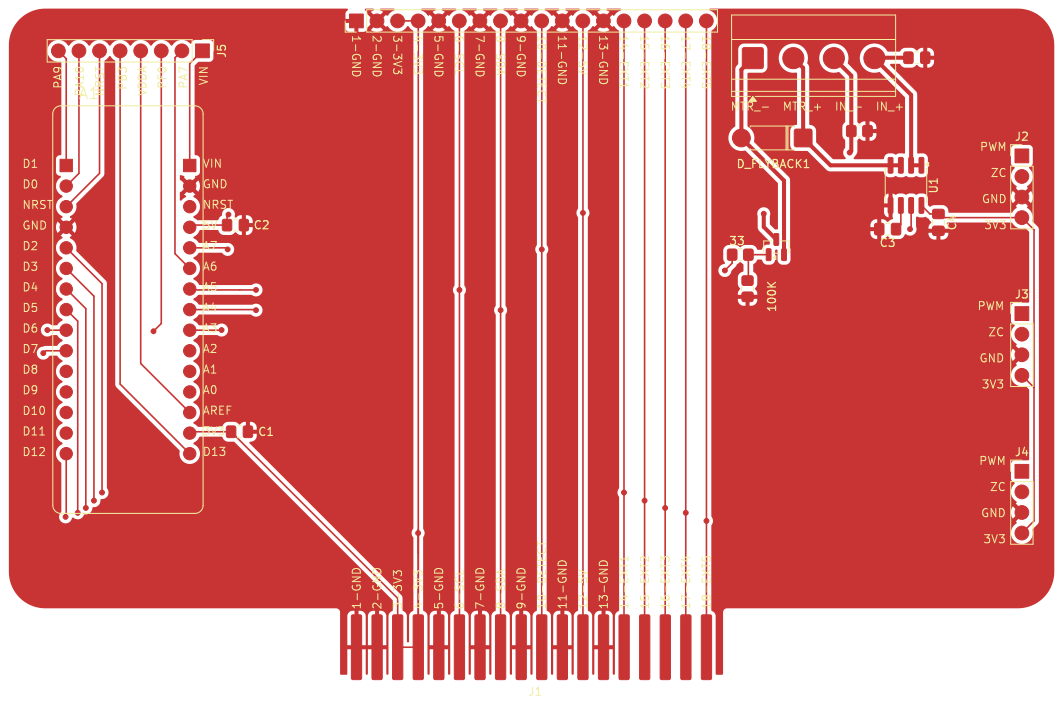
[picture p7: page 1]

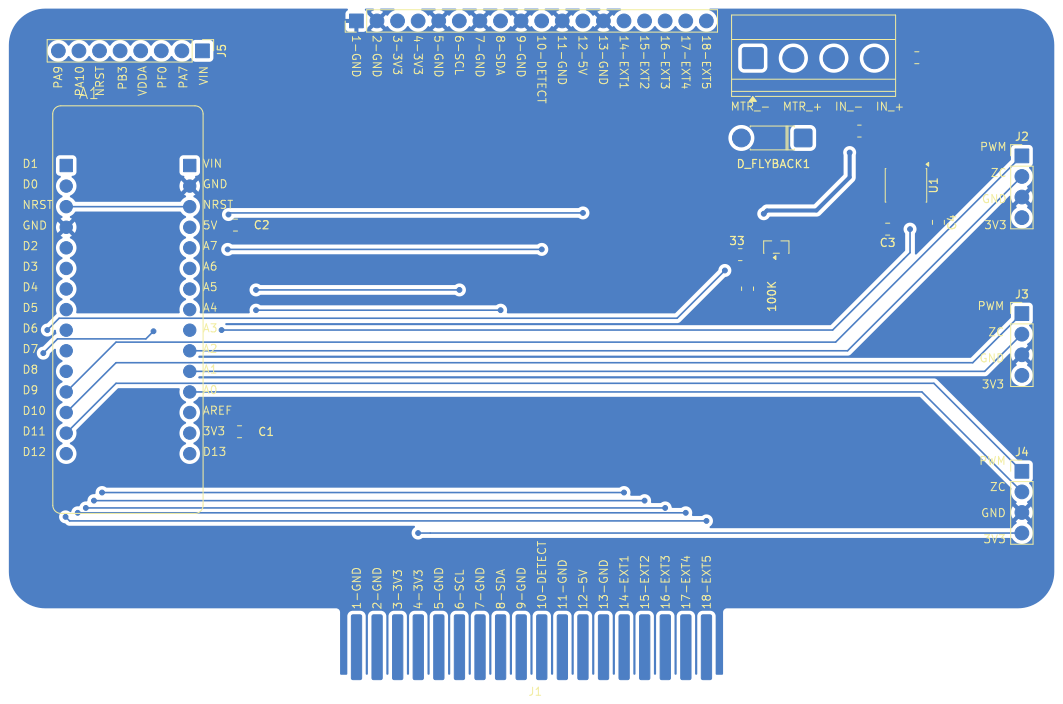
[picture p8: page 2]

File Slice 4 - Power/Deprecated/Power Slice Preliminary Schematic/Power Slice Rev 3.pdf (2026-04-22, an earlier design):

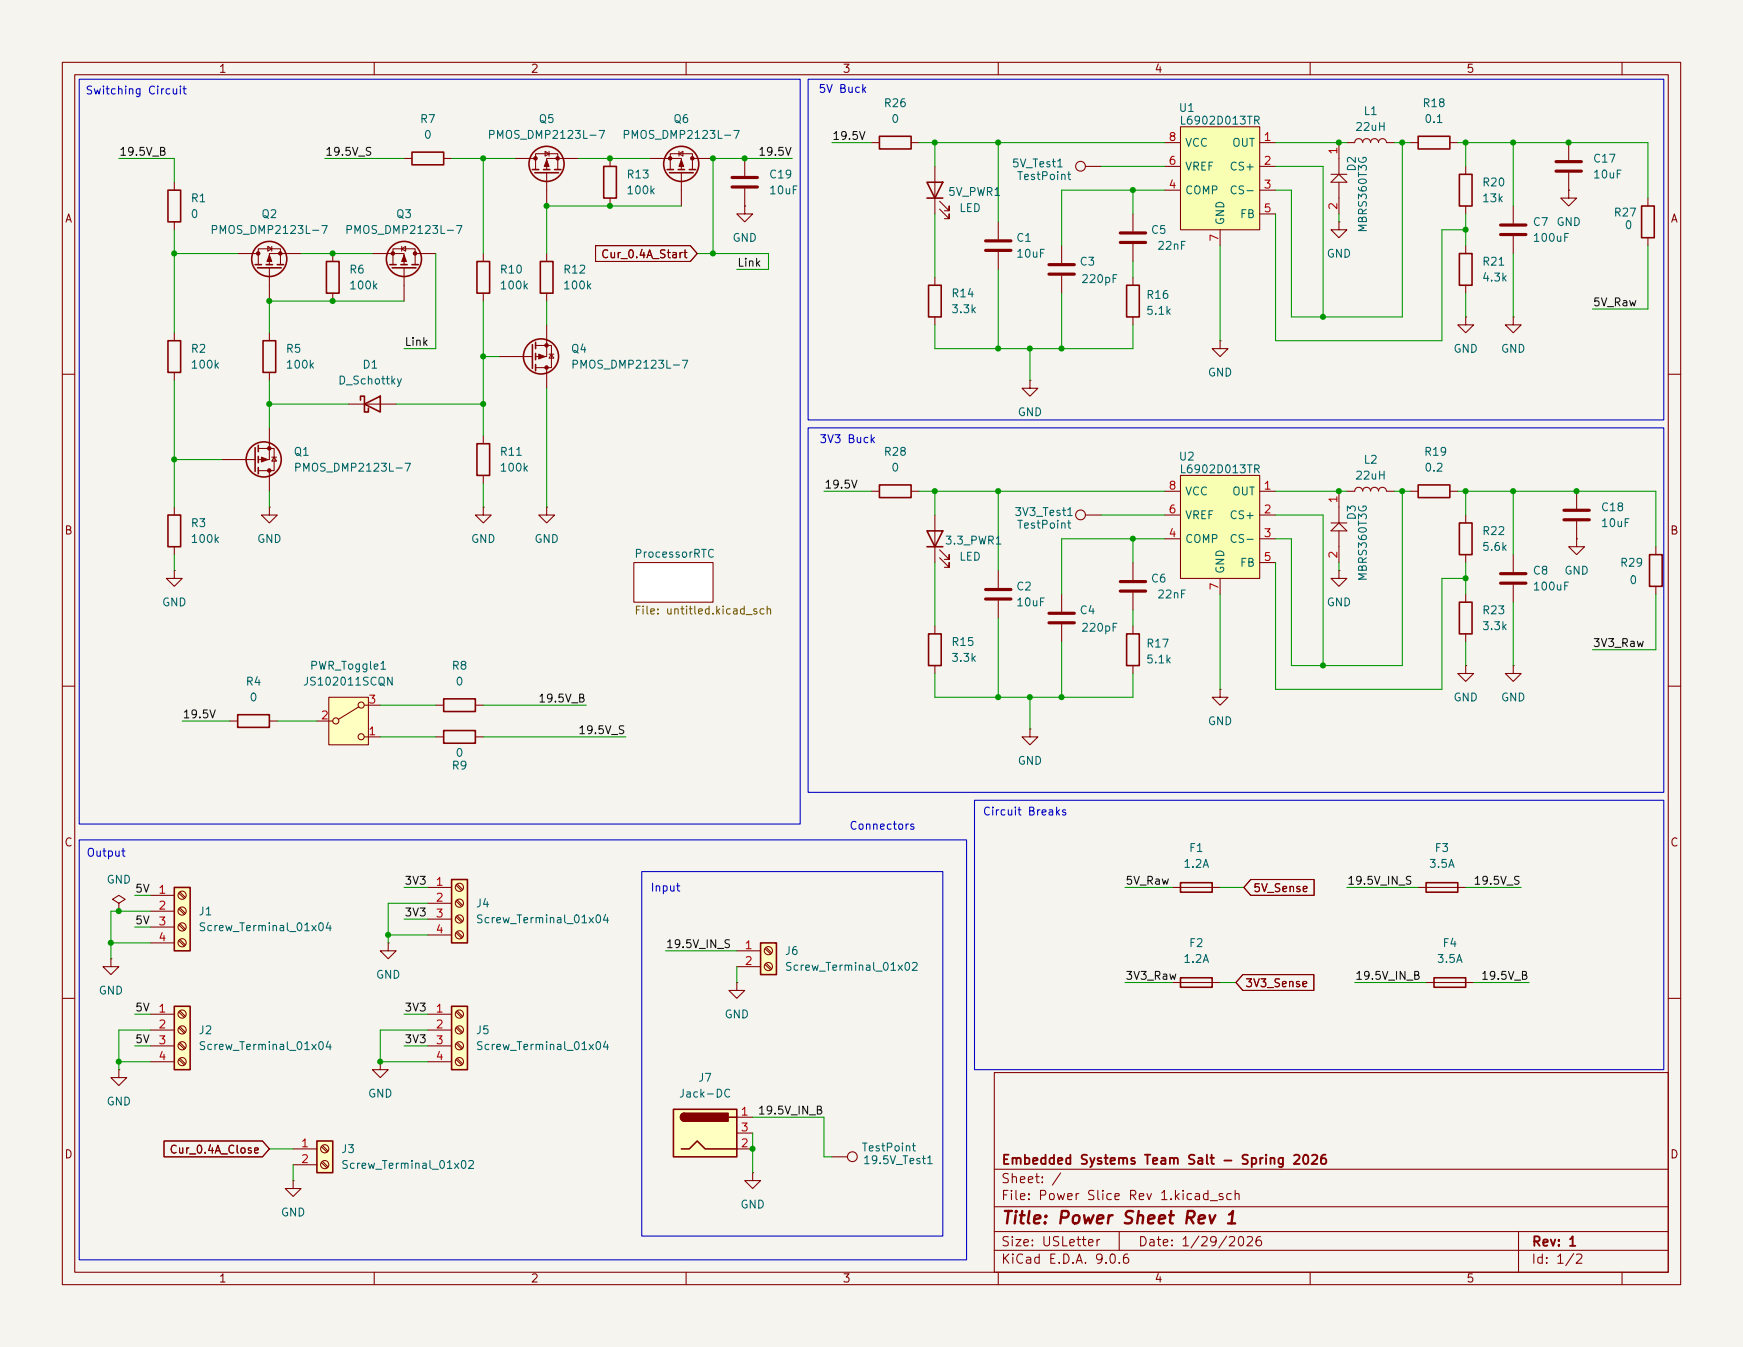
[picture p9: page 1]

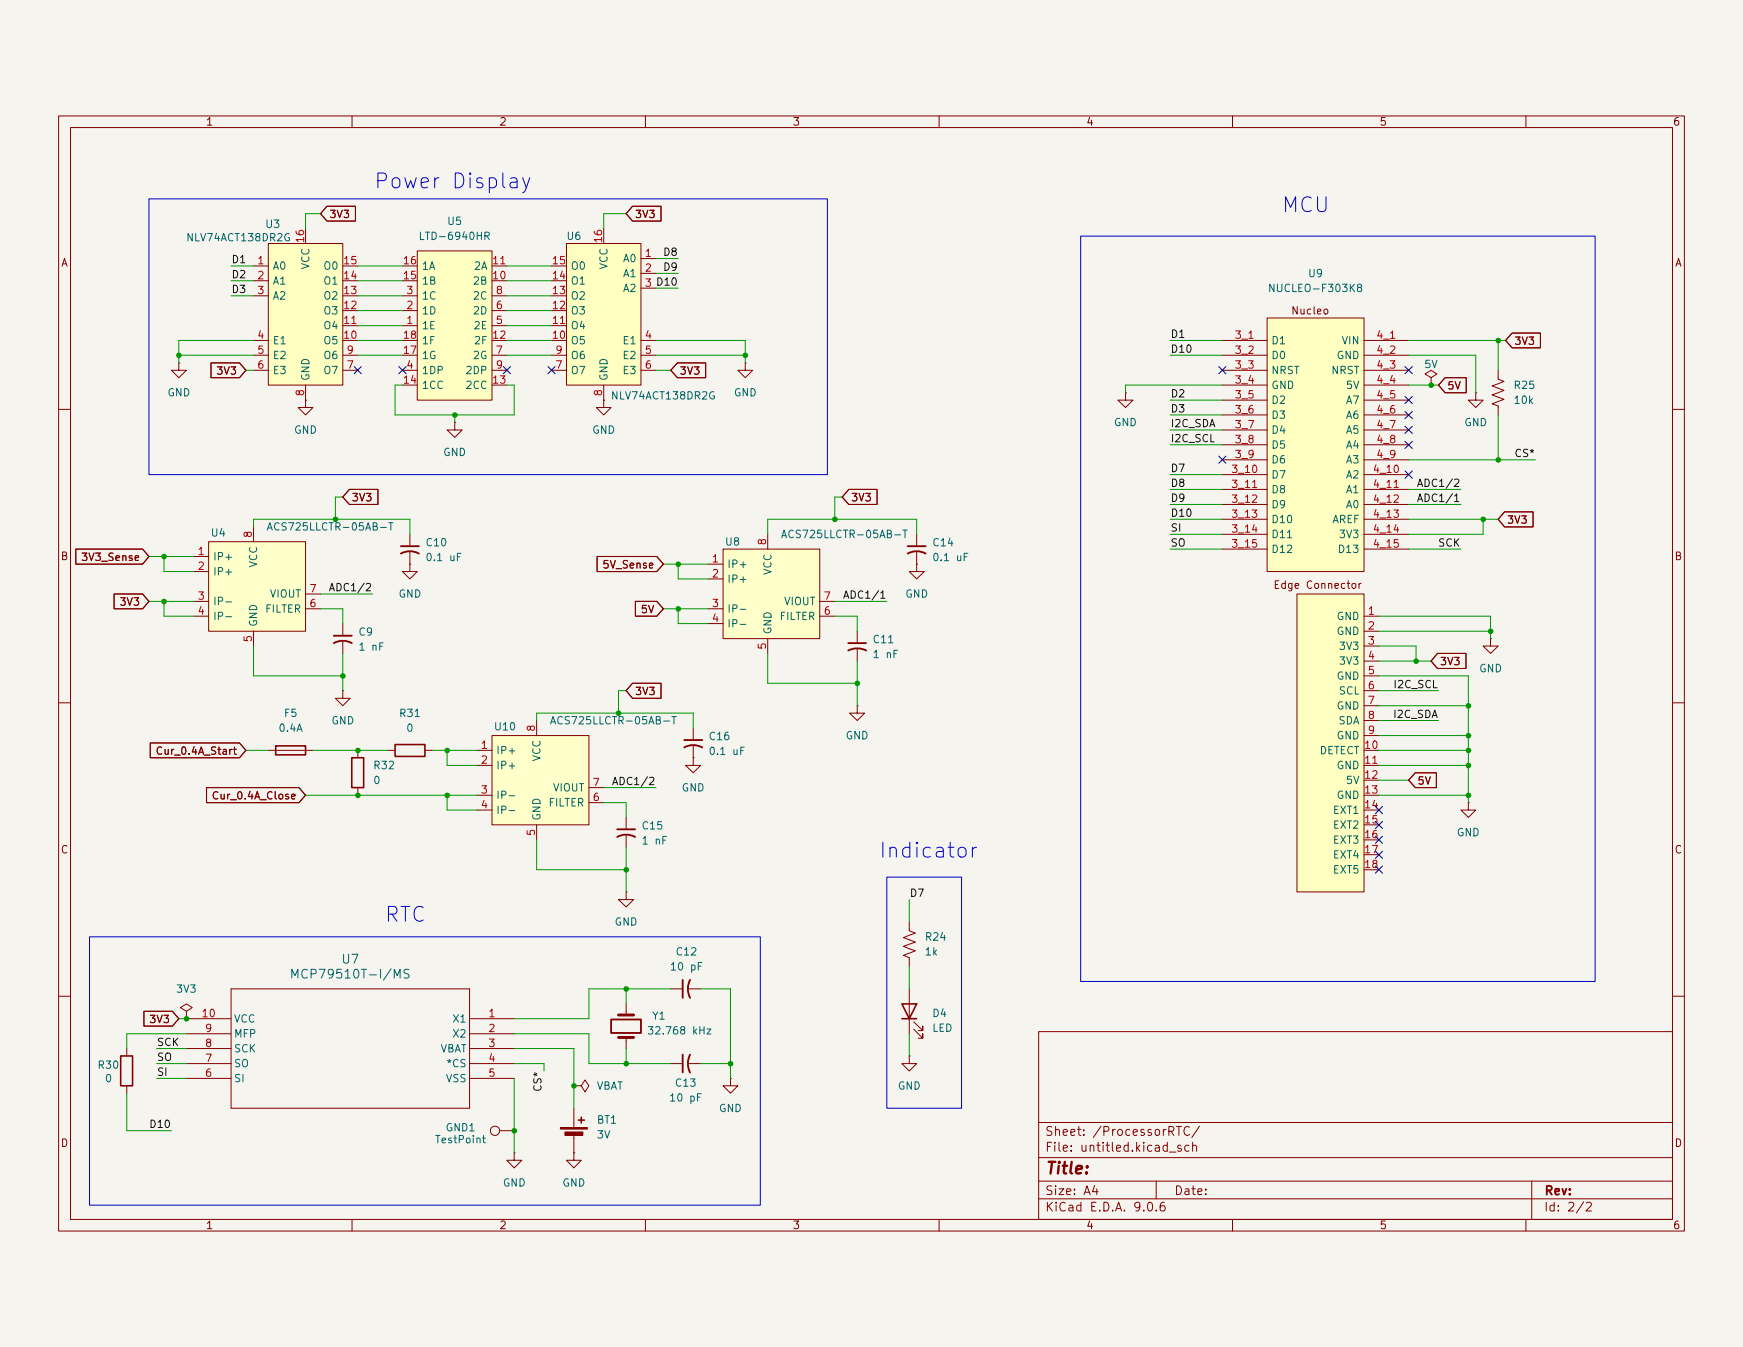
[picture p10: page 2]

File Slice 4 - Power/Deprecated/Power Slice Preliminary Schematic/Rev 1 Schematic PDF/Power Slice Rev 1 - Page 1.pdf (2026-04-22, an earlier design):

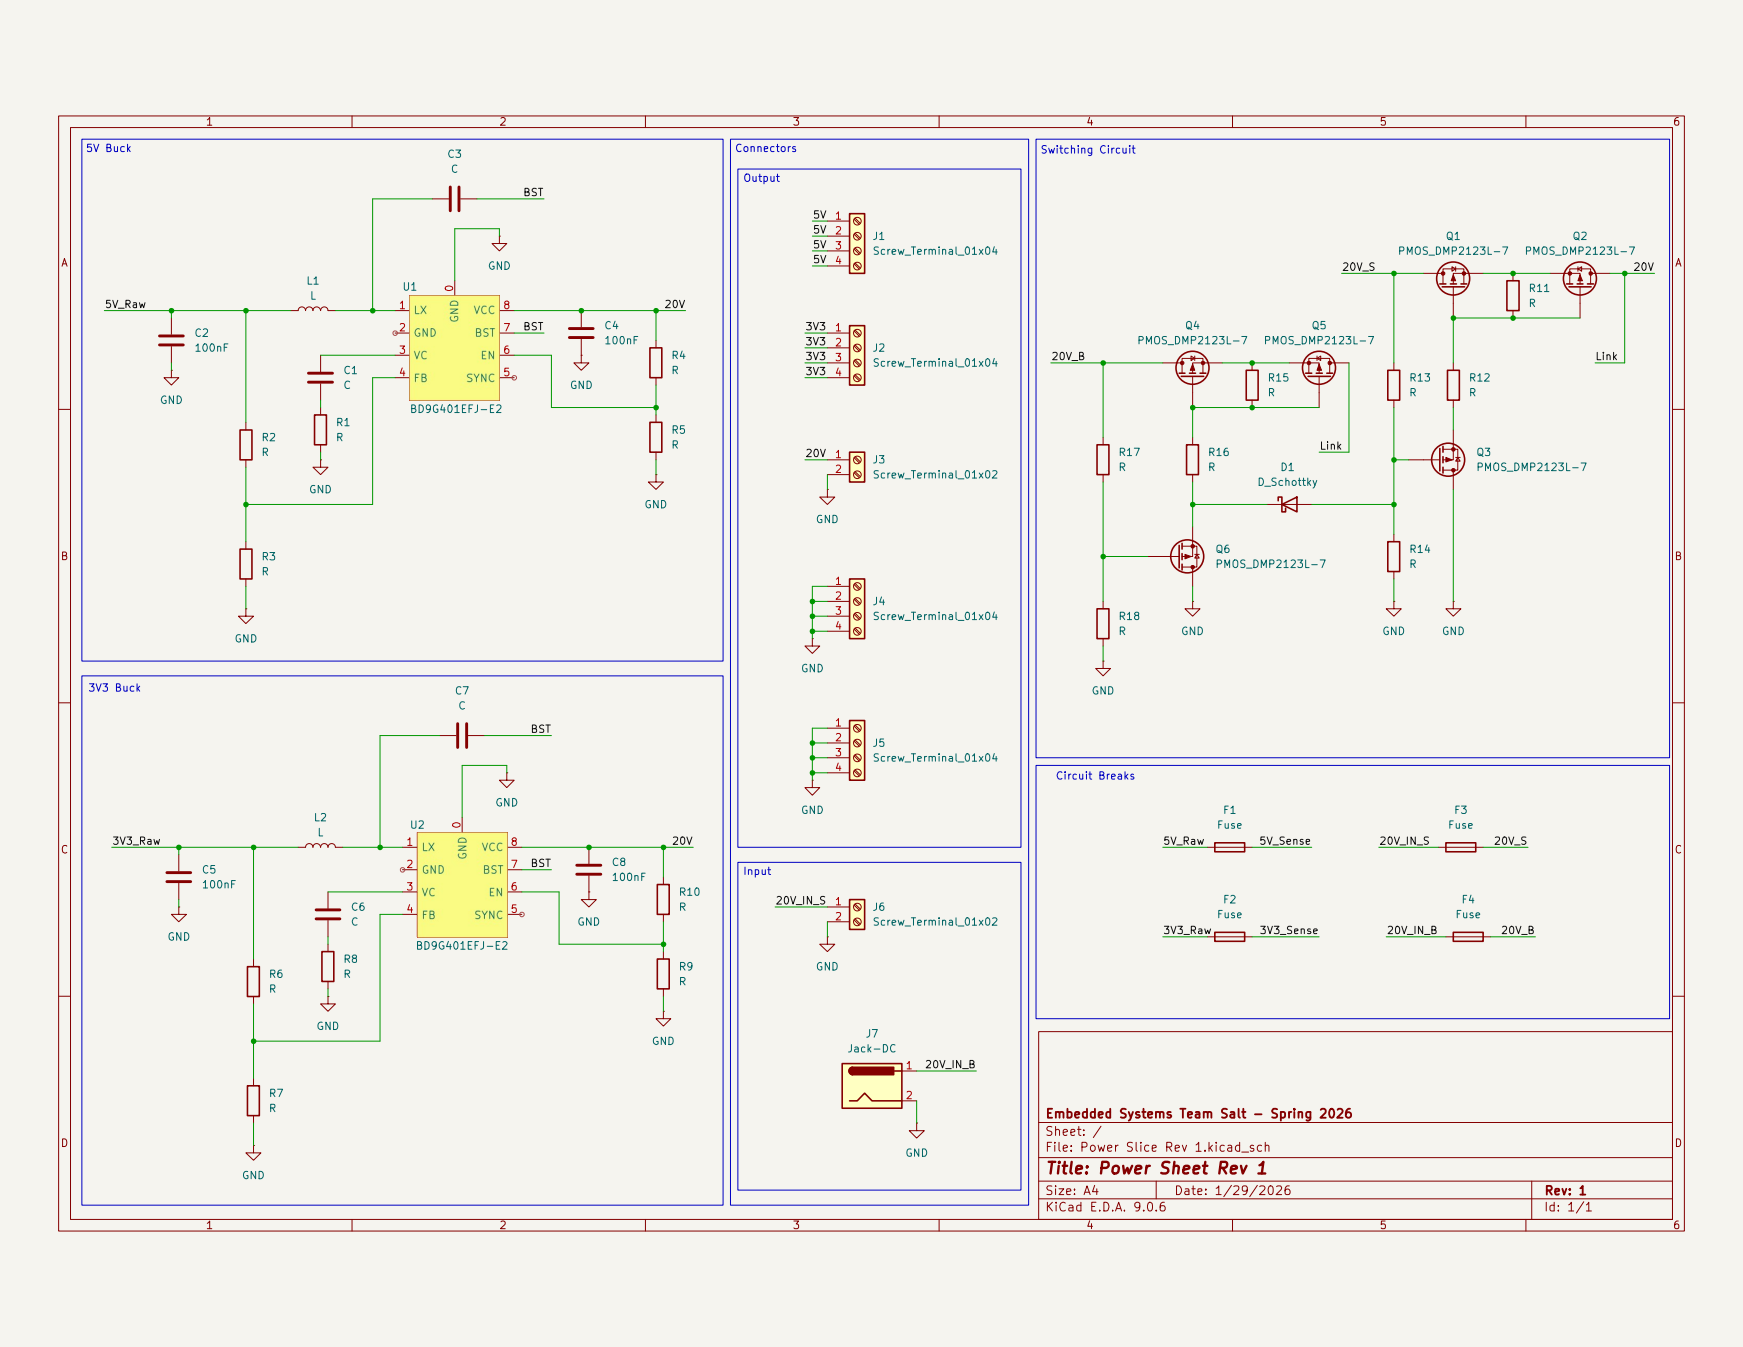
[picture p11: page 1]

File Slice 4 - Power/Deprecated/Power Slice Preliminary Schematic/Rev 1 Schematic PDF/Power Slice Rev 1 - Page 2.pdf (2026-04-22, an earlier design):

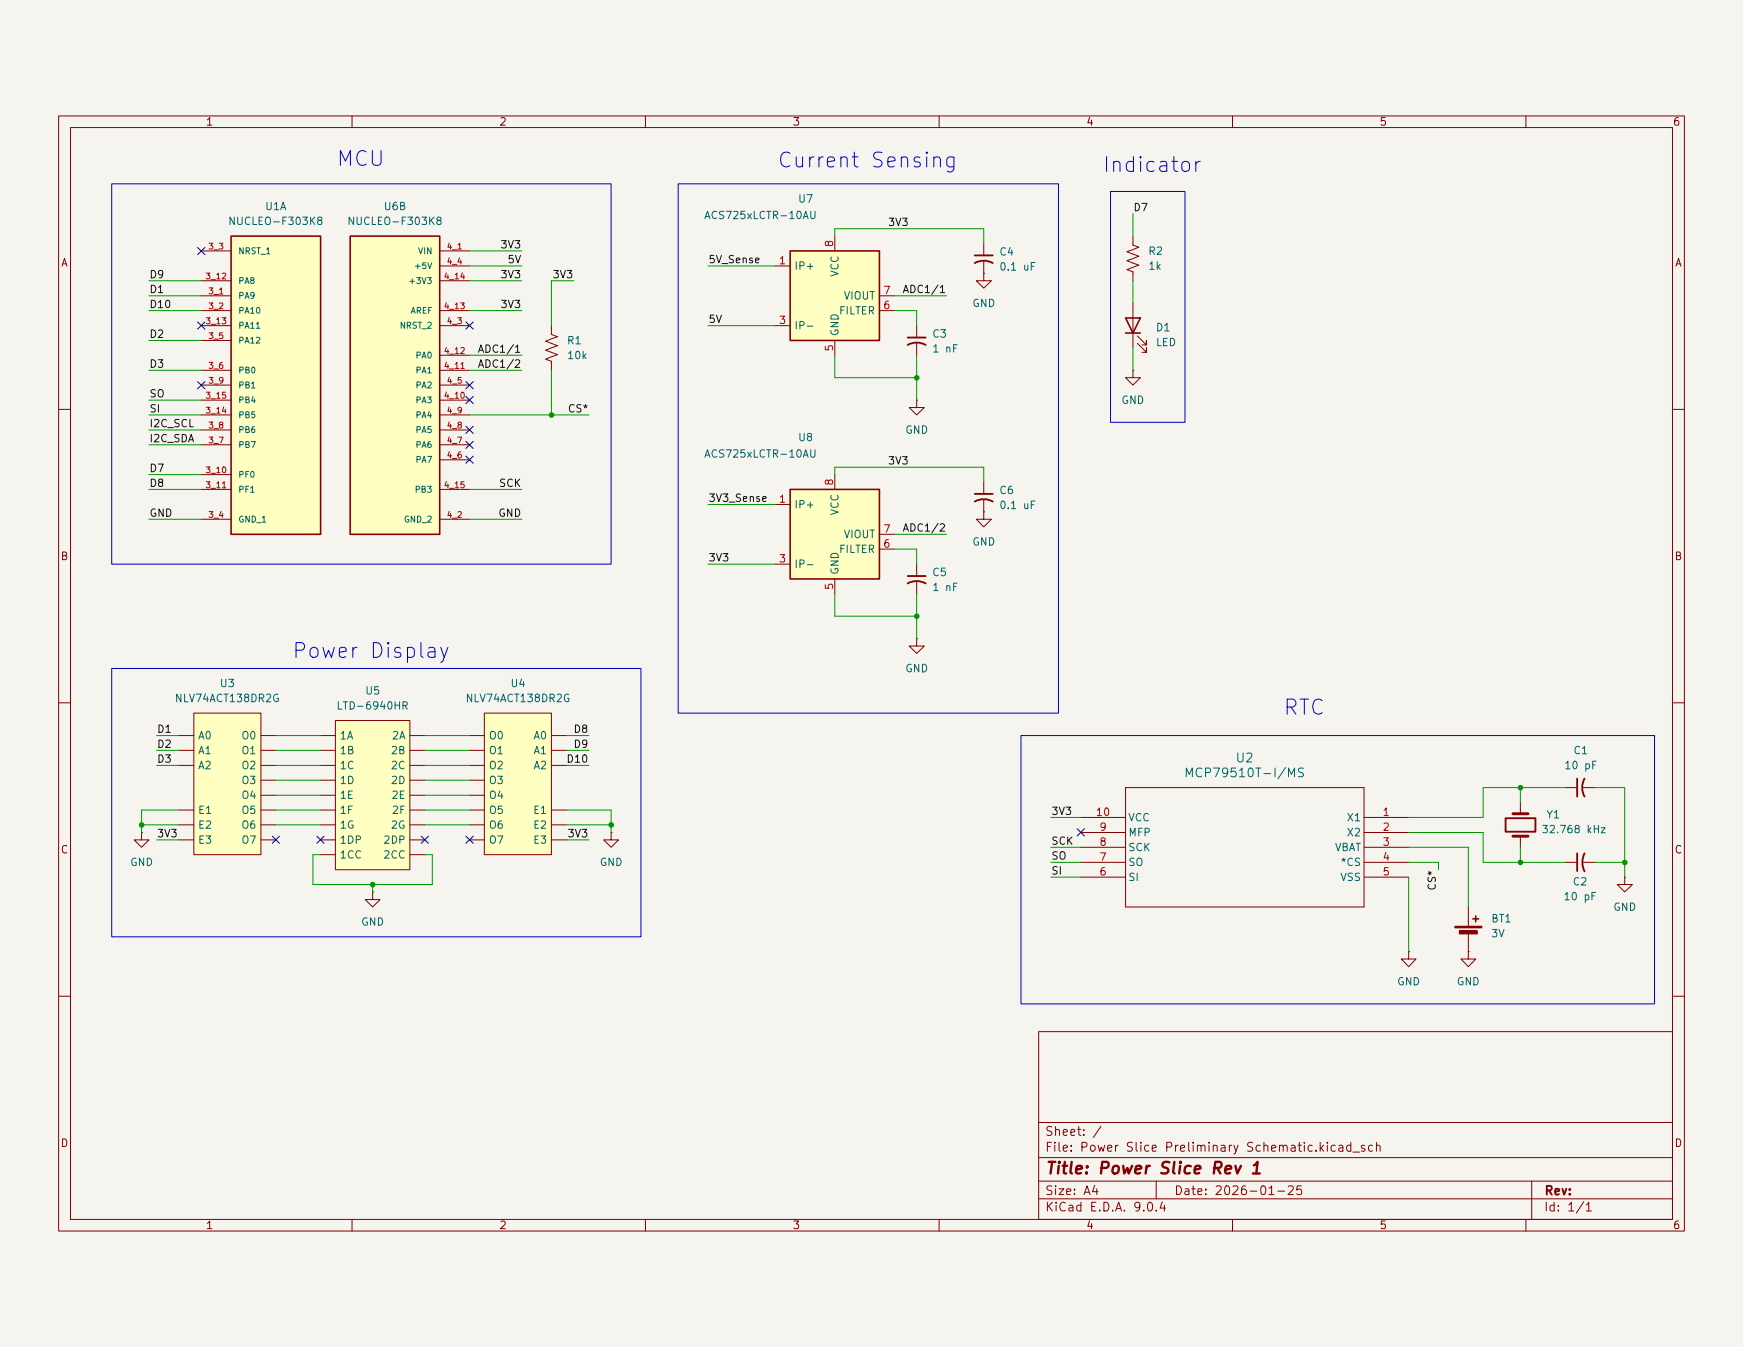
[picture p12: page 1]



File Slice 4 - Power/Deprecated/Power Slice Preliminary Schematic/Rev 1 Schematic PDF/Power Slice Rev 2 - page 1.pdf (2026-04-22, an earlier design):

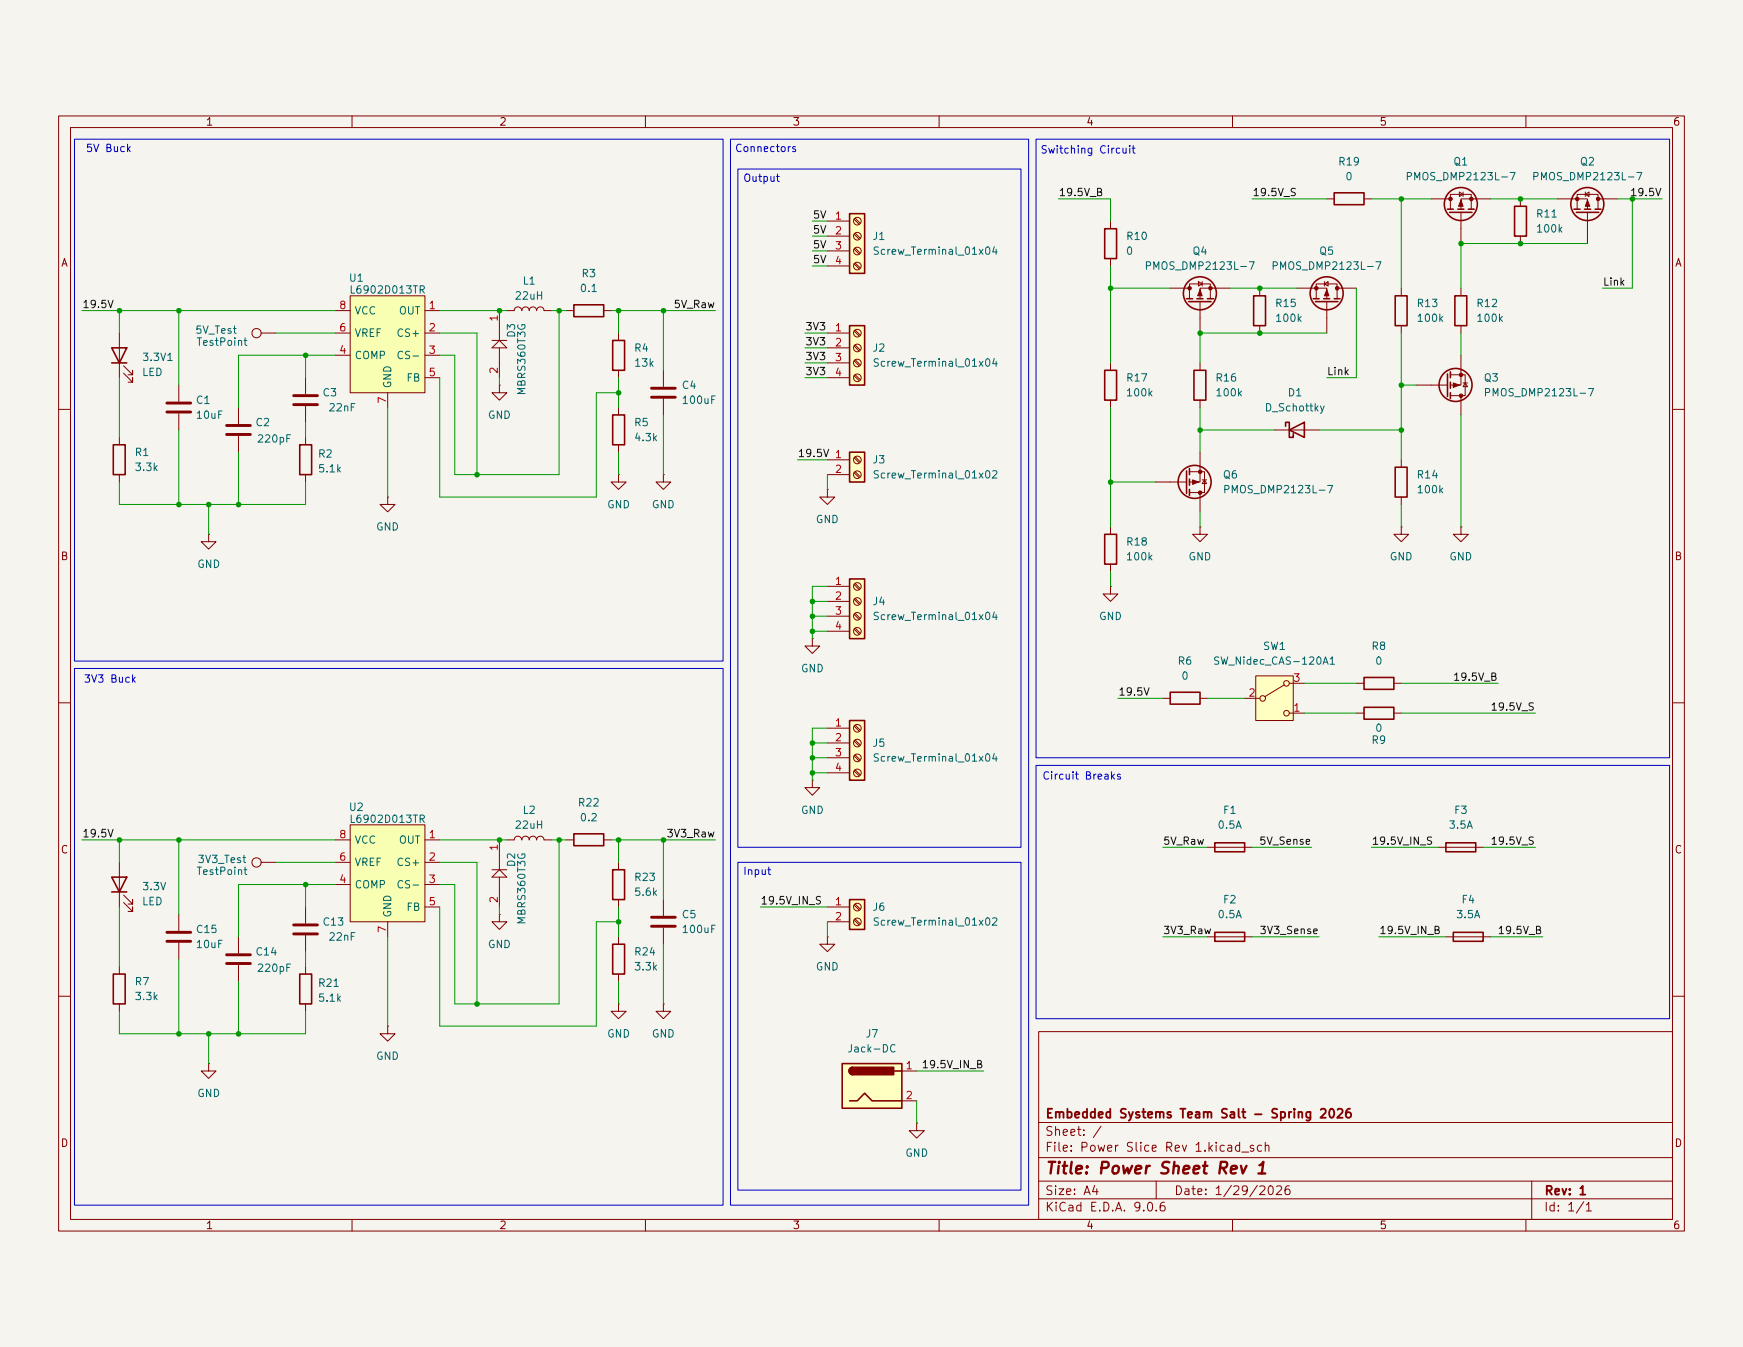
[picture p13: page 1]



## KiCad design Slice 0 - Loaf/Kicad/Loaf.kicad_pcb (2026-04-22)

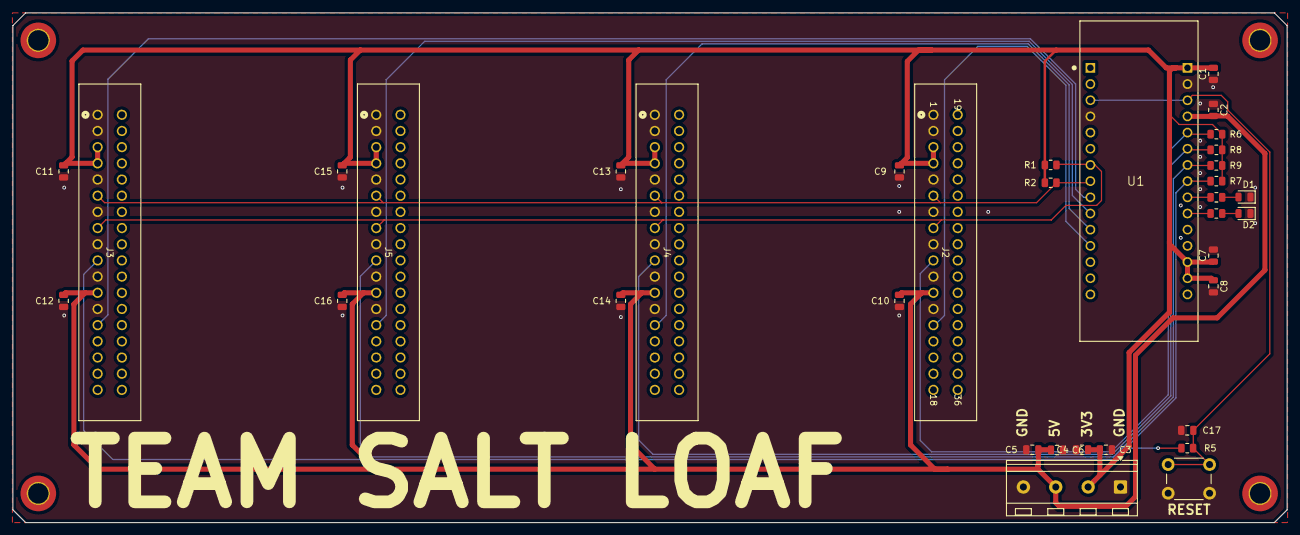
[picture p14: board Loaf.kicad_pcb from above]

Board: 2 copper layers, 200.0 x 80.0 mm, 35 parts (0 on the bottom side), 18 nets.

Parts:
C1, C2, C7, C8, C17: 0.1uF; C_0805_2012Metric
C3, C4, C5, C6, C9, C10, C11, C12, C13, C14, C15, C16: 10uF; C_0805_2012Metric
D1: USER LED1; LED_0805_2012Metric
D2: USER LED2; LED_0805_2012Metric
J1: Power Input Terminal; TerminalBlock_RND_205-00234_1x04_P5.08mm_Horizontal
J2, J3, J4, J5: 36p Edge Connector; EdgeConnector
R1, R2, R3, R4, R5, R6, R7, R8, R9: 4.7k; R_0805_2012Metric
SW1: BOOT; SW_PUSH_6mm_H5mm
U1: NUCLEO-F303K8; MODULE_NUCLEO-F303K8

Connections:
3V3: C1.2, C3.2, C4.2, C7.1, C8.1, C9.1, C11.1, C13.1, C15.1, J1.2, J2.3, J2.4, J3.3, J3.4, J4.3, J4.4, J5.3, J5.4, R1.2, R2.2, R5.2, R6.1, R7.1, R8.1, R9.1, U1.16 (VIN), U1.28 (AREF), U1.29 (3V3)
5V: C2.2, C5.1, C6.1, C10.1, C12.1, C14.1, C16.1, J1.3, J2.12, J3.12, J4.12, J5.12, U1.19 (5V)
DET_ACT: J5.10, R9.2, U1.22 (A6)
DET_OPT: J3.10, R7.2, U1.23 (A5)
DET_POW: J4.10, R8.2, U1.21 (A7)
DET_SENSE: J2.10, R6.2, U1.20 (A2)
EXT1_ACT: J5.14, U1.10 (F0)
EXT1_OPT: J3.14, U1.9 (B1)
EXT1_POW: J4.14, U1.11 (F1)
EXT1_SENSE: J2.14, U1.12 (A8)
GND: C1.1, C2.1, C3.1, C4.1, C5.2, C6.2, C7.2, C8.2, C9.2, C10.2, C11.2, C12.2, C13.2, C14.2, C15.2, C16.2, C17.2, D1.1 (K), D2.1 (K), J1.1, J1.4, J2.1, J2.2, J2.5, J2.7, J2.9, J2.11, J2.13, J3.1, J3.2, J3.5, J3.7, J3.9, J3.11, J3.13, J4.1, J4.2, J4.5, J4.7, J4.9, J4.11, J4.13, J5.1, J5.2, J5.5, J5.7, J5.9, J5.11, J5.13, SW1.1, U1.4 (GND), U1.17 (GND)
I2C_SCL: J2.6, J3.6, J4.6, J5.6, R2.1, U1.8 (B6)
I2C_SDA: J2.8, J3.8, J4.8, J5.8, R1.1, U1.7 (B7)
NRST: C17.1, R5.1, SW1.2, U1.3 (NRST), U1.18 (NRST)
unnamed: D1.2 (A), R4.2
unnamed: D2.2 (A), R3.2
unnamed: R3.1, U1.25 (A3)
unnamed: R4.1, U1.24 (A4)

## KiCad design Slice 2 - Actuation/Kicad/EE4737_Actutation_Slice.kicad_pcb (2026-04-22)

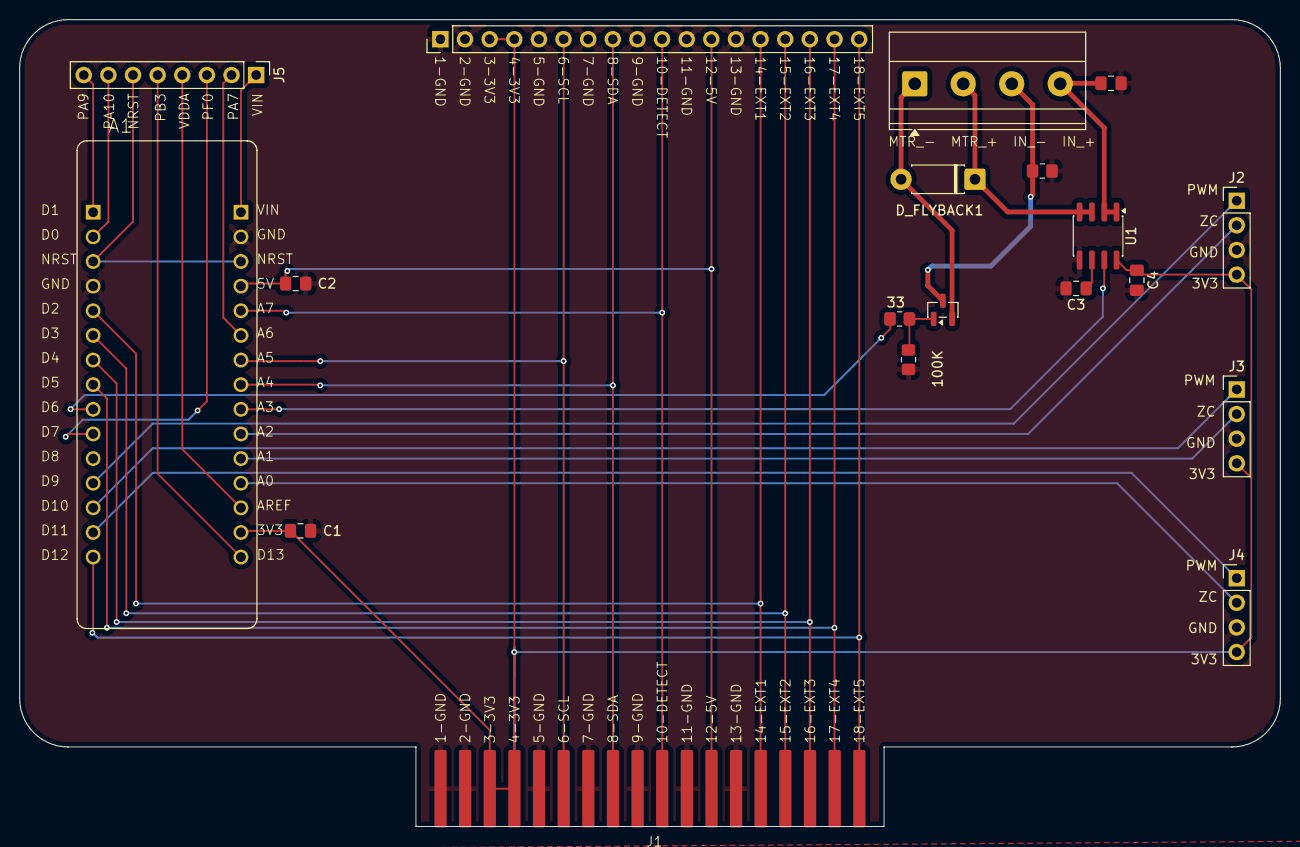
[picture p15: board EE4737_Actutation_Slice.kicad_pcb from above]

Board: 2 copper layers, 130.0 x 83.2 mm, 18 parts (0 on the bottom side), 33 nets.

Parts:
33: 33; R_0805_2012Metric_Pad1.20x1.40mm_HandSolder
100K: 100k; R_0805_2012Metric_Pad1.20x1.40mm_HandSolder
A1: nucleo32
C1, C2: 100nF; C_0805_2012Metric_Pad1.18x1.45mm_HandSolder
C3: 1nF; C_0805_2012Metric_Pad1.18x1.45mm_HandSolder
C4: .1uF; C_0805_2012Metric_Pad1.18x1.45mm_HandSolder
C_Motor1: 100nF; C_0805_2012Metric_Pad1.18x1.45mm_HandSolder
D_FLYBACK1: D; D_DO-41_SOD81_P7.62mm_Horizontal
J1: Conn_01x18; Team Salt Slice
J2, J3, J4: Conn_01x04; PinHeader_1x04_P2.54mm_Vertical
J5: Conn_01x08; PinHeader_1x08_P2.54mm_Vertical
J_motor1: Screw_Terminal_01x04; TerminalBlock_Phoenix_MKDS-1,5-4_1x04_P5.00mm_Horizontal
Q_Motor1: Q_NMOS_GDS; SOT-23
R_MPD2: 0; R_0805_2012Metric_Pad1.20x1.40mm_HandSolder
U1: ACS725xLCTR-50AB; SOIC-8_3.9x4.9mm_P1.27mm

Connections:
3V3: A1.4.14 (VDD), C1.1, C4.1, J1.3, J1.4, J2.4, J3.4, J4.4, U1.8 (VCC)
5V: A1.4.4 (5V), C2.1, J1.12
CS+19V5: C_Motor1.1, J_motor1.4, U1.1 (IP+), U1.2 (IP+)
CS-19V5: D_FLYBACK1.1 (K), J_motor1.2, U1.3 (IP-), U1.4 (IP-)
DETECT: A1.4.5 (PA2), J1.10
EXT1: A1.3.5 (PA12), J1.14
EXT2: A1.3.6 (PB0), J1.15
EXT3: A1.3.7 (PB7), J1.16
EXT4: A1.3.8 (PB6), J1.17
EXT5: A1.3.15 (PB4), J1.18
EXT_19V5_-: J_motor1.3, Q_Motor1.3 (S), R_MPD2.1
GND: 100K.2, A1.3.4 (GND), A1.4.2 (GND), C1.2, C2.2, C3.2, C4.2, C_Motor1.2, J1.1, J1.2, J1.5, J1.7, J1.9, J1.11, J1.13, J2.3, J3.3, J4.3, R_MPD2.2, U1.5 (GND)
MTR_-: D_FLYBACK1.2 (A), J_motor1.1, Q_Motor1.2 (D)
MotorPWM: 33.1, A1.3.9 (PB1)
NRST: A1.3.3 (NRST), A1.4.3 (NRST), J5.6
unnamed: 33.2, 100K.1, Q_Motor1.1 (G)
unnamed: C3.1, U1.6 (FILTER)
PA4: A1.4.9 (PA4), U1.7 (VIOUT)
PA7: A1.4.6 (PA7), J5.2
PA9: A1.3.1 (PA9), J5.8
PA10: A1.3.2 (PA10), J5.7
PB3: A1.4.15 (PB3), J5.5
PF0: A1.3.10 (PF0), J5.3
PWM_1: A1.3.12 (PA8), J2.1
PWM_2: A1.3.13 (PA11), J3.1
PWM_3: A1.3.14 (PB5), J4.1
SCL: A1.4.7 (PA6), J1.6
SDA: A1.4.8 (PA5), J1.8
VDDA: A1.4.13 (VDDA), J5.4
VIN: A1.4.1 (VIN), J5.1
ZC_1: A1.4.10 (PA3), J2.2
ZC_2: A1.4.11 (PA1), J3.2
ZC_3: A1.4.12 (PA0), J4.2

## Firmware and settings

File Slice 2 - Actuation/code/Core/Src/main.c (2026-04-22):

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
/* Includes ------------------------------------------------------------------*/
#include "main.h"

/* USER CODE BEGIN Includes */
#include <stdio.h>
#include <stdbool.h>
/* USER CODE END Includes */

ADC_HandleTypeDef hadc2;

TIM_HandleTypeDef htim1;
TIM_HandleTypeDef htim2;

UART_HandleTypeDef huart1;
DMA_HandleTypeDef hdma_usart1_rx;

/* USER CODE BEGIN PV */
uint32_t adc2_val = 0;
uint32_t adcF_val = 0;

#define MY_SLOT_ID 0x02
#define RX_BUFFER_SIZE 1024
char rxBuffer[RX_BUFFER_SIZE];

//dim pvs
volatile uint8_t dim1 = 50;
volatile uint8_t dim2 = 50;
volatile uint8_t dim3 = 50;
/* USER CODE END PV */

void SystemClock_Config(void);
static void MX_GPIO_Init(void);
static void MX_DMA_Init(void);
static void MX_USART1_UART_Init(void);
static void MX_ADC2_Init(void);
static void MX_TIM2_Init(void);
static void MX_TIM1_Init(void);
/* USER CODE BEGIN 0 */
void respondToLoaf()
{
    // Team Salt: Implement your loaf response logic here. Called whenever the loaf requests a packet from this slice
    // I am expecting to see a message in the format: ">VARNAME:VALUE>VARNAME2:VALUE...\n"
    // VALUE can be a string or a number, and there can be any number of variable assignments in a single packet

    HAL_GPIO_TogglePin(GPIOB, GPIO_PIN_3); // Toggle onboard LED to indicate response
    HAL_Delay(5);


    char response[128];
    snprintf(response, sizeof(response), ">dummyVariable:%.2f>dummyString:\"%s\"\n", 3.14, "Dispensing Salt!");
    HAL_UART_Transmit(&huart1, (uint8_t *)response, sizeof(response), HAL_MAX_DELAY);
}

void parseUARTBuffer(char *buffer, size_t len)
{
    char cmd[RX_BUFFER_SIZE];
    size_t cmdIndex = 0;
    bool inCommand = false;

    for (size_t i = 0; i < len; i++)
    {
        char c = buffer[i];

        if (c == 0x99 && i + 1 < len && buffer[i + 1] == MY_SLOT_ID) // If the loaf is requesting a packet from this slice
        {
            respondToLoaf();
            buffer[i] = '\0'; // Clear processed command
            buffer[i + 1] = '\0';
            i++;
        }
        else if (c == '>')
        {
            // If we were already building a command, finalize it
            if (inCommand && cmdIndex > 0)
            {
                cmd[cmdIndex] = '\0';
         //       processCommand(cmd);
                cmdIndex = 0;
            }

            // Start a new command
            inCommand = true;
            buffer[i] = '\0'; // Clear processed command
        }
        else if (c == '\n')
        {
            // End of packet — flush any active command
            if (inCommand && cmdIndex > 0)
            {
                cmd[cmdIndex] = '\0';
          //      processCommand(cmd);
            }

            // Reset state
            inCommand = false;
            cmdIndex = 0;
            buffer[i] = '\0'; // Clear processed command
        }
        else if (inCommand)
        {
            // Accumulate command characters safely
            if (cmdIndex < (RX_BUFFER_SIZE - 1))
            {
                cmd[cmdIndex++] = c;
                buffer[i] = '\0'; // Clear processed command
            }
            else
            {
                // Overflow protection: discard oversized command
                cmdIndex = 0;
                inCommand = false;
            }
        }
    }
}

void HAL_UART_RxCpltCallback(UART_HandleTypeDef *huart) {
    if (huart->Instance == USART1) {
        // Process the received data in rxBuffer
        // Restart DMA reception
        HAL_UART_Receive_DMA(&huart1, (uint8_t *)rxBuffer, RX_BUFFER_SIZE);
    }
}
/* USER CODE END 0 */

/**
  * @brief  The application entry point.
  * @retval int
  */
int main(void)
{

  /* MCU Configuration--------------------------------------------------------*/

  /* Reset of all peripherals, Initializes the Flash interface and the Systick. */
  HAL_Init();

  /* Configure the system clock */
  SystemClock_Config();

  /* Initialize all configured peripherals */
  MX_GPIO_Init();
  MX_DMA_Init();
  MX_USART1_UART_Init();
  MX_ADC2_Init();
  MX_TIM2_Init();
  MX_TIM1_Init();
  /* USER CODE BEGIN 2 */
  HAL_UART_Receive_DMA(&huart1, (uint8_t *)rxBuffer, RX_BUFFER_SIZE);
  HAL_TIM_PWM_Start(&htim1, TIM_CHANNEL_1);
  /* USER CODE END 2 */

  /* Infinite loop */
  /* USER CODE BEGIN WHILE */
  while (1)
  {
	  HAL_GPIO_TogglePin(GPIOB, GPIO_PIN_1);
	  	  	  HAL_Delay(1000);


	  	  HAL_ADC_Start(&hadc2);
	  	  	  if (HAL_ADC_PollForConversion(&hadc2, 100) == HAL_OK){
	  	  		 adc2_val = HAL_ADC_GetValue(&hadc2);
	  	  		 adcF_val = (adc2_val - 2000);
	  	  	  }
	  	  	  HAL_ADC_Stop(&hadc2);
	  	  	 HAL_Delay(100);

	  	  	 parseUARTBuffer(rxBuffer, RX_BUFFER_SIZE);
	  	  	 HAL_Delay(5);

	 dim1 = 20;
	 dim2 = 20;
	 dim3 = 20;

	 __HAL_TIM_SET_COMPARE(&htim1, TIM_CHANNEL_1, 50);

	 HAL_GPIO_TogglePin(GPIOB, GPIO_PIN_5);
    /* USER CODE END WHILE */

    /* USER CODE BEGIN 3 */
  }
  /* USER CODE END 3 */
}

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
/* USER CODE BEGIN 4 */
void delay_us(volatile uint16_t us)
{
    while(us--) {
        for(volatile int i=0;i<10;i++);
    }
}

void fire_triac(GPIO_TypeDef* port, uint16_t pin)
{
    HAL_GPIO_WritePin(port, pin, GPIO_PIN_SET);
    delay_us(100);  // trigger pulse
    HAL_GPIO_WritePin(port, pin, GPIO_PIN_RESET);
}

void HAL_GPIO_EXTI_Callback(uint16_t GPIO_Pin)
{
    uint16_t delay_time;

    if (GPIO_Pin == GPIO_PIN_3) // ZC1
    {
        delay_time = (100 - dim1) * 80;
        delay_us(delay_time);
        fire_triac(GPIOA, GPIO_PIN_8);
    }
    else if (GPIO_Pin == GPIO_PIN_1) // ZC2
    {
        delay_time = (100 - dim2) * 80;
        delay_us(delay_time);
        fire_triac(GPIOA, GPIO_PIN_11);
    }
    else if (GPIO_Pin == GPIO_PIN_0) // ZC3
    {
        delay_time = (100 - dim3) * 80;
        delay_us(delay_time);
        fire_triac(GPIOB, GPIO_PIN_5);
    }
}

/* USER CODE END 4 */
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


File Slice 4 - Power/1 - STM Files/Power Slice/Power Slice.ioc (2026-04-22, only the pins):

Mcu.UserName=STM32F303K8Tx
PA0.Signal=SharedAnalog_PA0
PA1.Signal=SharedAnalog_PA1
PA13.GPIO_Label=SWDIO
PA13.Signal=SYS_JTMS-SWDIO
PA14.GPIO_Label=SWCLK
PA14.Signal=SYS_JTCK-SWCLK
PA15.GPIO_Label=VCP_RX
PA15.Signal=USART2_RX
PA2.Signal=SharedAnalog_PA2
PA3.Signal=ADC1_IN4
PA4.Signal=GPIO_Output
PB0.Signal=GPIO_Output
PB3.Signal=SPI1_SCK
PB4.Signal=SPI1_MISO
PB5.Signal=SPI1_MOSI
PB6.Signal=USART1_TX
PB7.Signal=USART1_RX

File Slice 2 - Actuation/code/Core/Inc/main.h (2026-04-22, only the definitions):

#define MCO_Pin GPIO_PIN_0
#define MCO_GPIO_Port GPIOF
#define SWDIO_Pin GPIO_PIN_13
#define SWDIO_GPIO_Port GPIOA
#define SWCLK_Pin GPIO_PIN_14
#define SWCLK_GPIO_Port GPIOA
#define VCP_RX_Pin GPIO_PIN_15
#define VCP_RX_GPIO_Port GPIOA

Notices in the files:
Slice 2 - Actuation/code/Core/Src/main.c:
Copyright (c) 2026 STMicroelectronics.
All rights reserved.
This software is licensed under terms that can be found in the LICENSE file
